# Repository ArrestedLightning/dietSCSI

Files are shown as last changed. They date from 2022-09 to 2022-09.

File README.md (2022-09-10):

dietSCSI logo

The dietSCSI is a SCSI disk emulator, designed to be low-cost while remaining highly functional.

Features
----------

* SMT-first design, optimized for modern low-cost assembly services
  * Target price of ~$10 each in small quantities from JLCPCB, fully assembled
  * This implies that the retail price for a fully-assembled board could be $20 with a 100% markup
* Can be [hand-assembled](https://youtu.be/Q2M2qIhKqx8) using only parts that are [readily available from DigiKey](https://www.digikey.com/short/dphdzd52) (Except for the STM32 microcontroller, but those aren't readily available anywhere at the moment)
* Integrated DB25 and 50-pin IDC connectors on one board.  A single PCB design covers multiple use cases, ideal for easy switching between multiple computers
  * This also means that you can use the dietSCSI itself as a DB-25 to 50-pin SCSI adapter in a pinch
* On-board termination (jumper-selectable)
* Design files for [3D printed cases](https://github.com/ArrestedLightning/dietSCSI/blob/main/Mechanical/README.md) are available in variants for both portable usage and 3.5" hard disk replacement
* 0.1" headers for external activity LEDs
* Can be powered via SCSI termination power or from an external source
* Designed to run firmware based on the open source [BlueSCSI firmware](https://github.com/erichelgeson/BlueSCSI/)
* [Default firmware](https://github.com/ArrestedLightning/dietSCSI_firmware/) has both [USB image passthrough](https://youtu.be/Y3mzckQU518) and [USB firmware update support](https://youtu.be/odwWRFDpAHM) built in (see the [usage page](https://github.com/ArrestedLightning/dietSCSI/blob/main/docs/usage.md) for details).

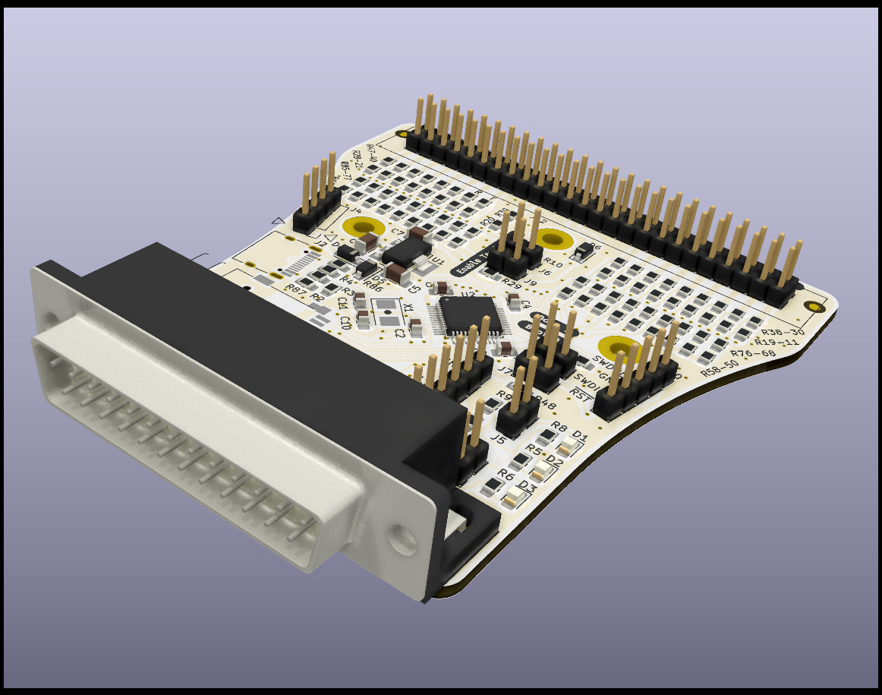
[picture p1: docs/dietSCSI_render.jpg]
dietSCSI PCB image


Documentation
--------
* [Ordering assembled boards from JLCPCB](https://github.com/ArrestedLightning/dietSCSI/blob/main/docs/ordering_boards.md)
* [Hand assembly](https://github.com/ArrestedLightning/dietSCSI/blob/main/docs/hand_assembly.md)
* [Finishing](https://github.com/ArrestedLightning/dietSCSI/blob/main/docs/finishing.md)
* [Usage](https://github.com/ArrestedLightning/dietSCSI/blob/main/docs/usage.md)
* [Test Results](https://github.com/ArrestedLightning/dietSCSI/blob/main/docs/testresults.md)

Acknowledgments
--------

* The [ARDSCSuino-stm32](https://github.com/ztto/ArdSCSino-stm32) project for the original implementation of STM32-to-SCSI hardware and firmware
* [This TI document](https://www.ti.com/lit/an/slla035/slla035.pdf) on SCSI termination
* The [BlueSCSI project](https://github.com/erichelgeson/BlueSCSI/) for their work on the firmware

BlueSCSI is a registered trademark.  This project is not affiliated with or endorsed by the BlueSCSI project.  Please do not contact the BlueSCSI people for support; use GitHub discussions or email me directly.

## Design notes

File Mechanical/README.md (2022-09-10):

Cases
==================
Several 3D-printable case options are available for the dietSCSI.  Cases were designed using FreeCAD; all designs are in the same CAD file.  You will need 4 M3x5mm machine screws to attach the board to the case and hold on the lid.  The internal versions are also designed to use M3 screws for the mounting fasteners.

Portable
---------

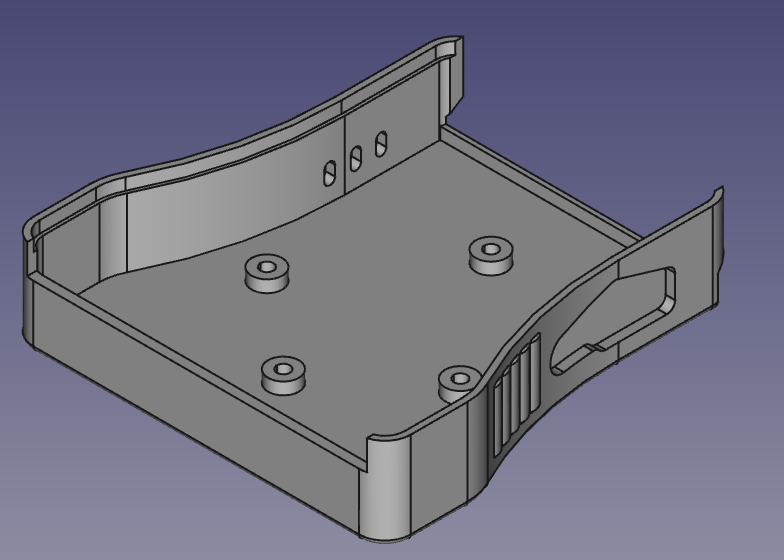
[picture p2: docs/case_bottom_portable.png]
Portable case render


This case is designed for external use.  It could also be used internally if mounted using velcro or adhesive tape.

3.5" Compact
--------
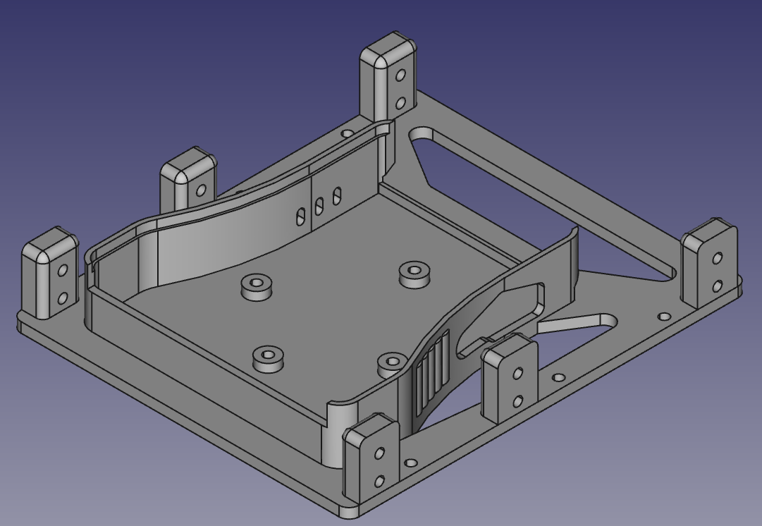
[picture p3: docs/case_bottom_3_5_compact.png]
3.5 compact case render


This case is designed for internal use.  It is smaller so it is printable on smaller printers.  Its size is more or less constrained by the standard 3.5" drive mounting holes.  This means that it will sit further in compared to a real hard drive.  If your SCSI cable is only just long enough for a standard drive, it may not work with this enclosure.  The standard SCSI cable included with a Macintosh Classic II is just barely long enough to reach when using this enclosure.  Mounting holes are available on both the sides and the bottom, allowing for mounting options that should work with most computers.

3.5" Extended
--------
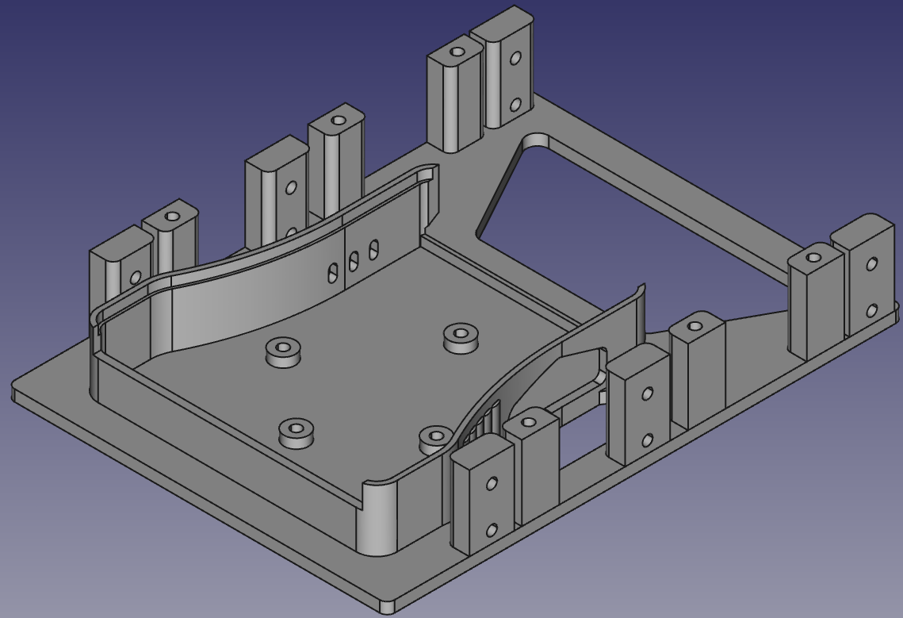
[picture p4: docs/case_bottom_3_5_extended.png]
3.5 extended case render


This case is also designed for internal use.  It is designed to be closer to the size of a standard 3.5" drive, which means that the SCSI connector should come just about up to the edge.  This should be more compatible with more systems.  It is also designed so that it can be mounted upside down using either the side or the bottom mounting holes, which may be necessary to get the SCSI connector in the correct orientation.  In particular, this feature was designed with the Macintosh LC family in mind.  I have not tested this, though, so I can't guarantee it will fit.

Lids
--------
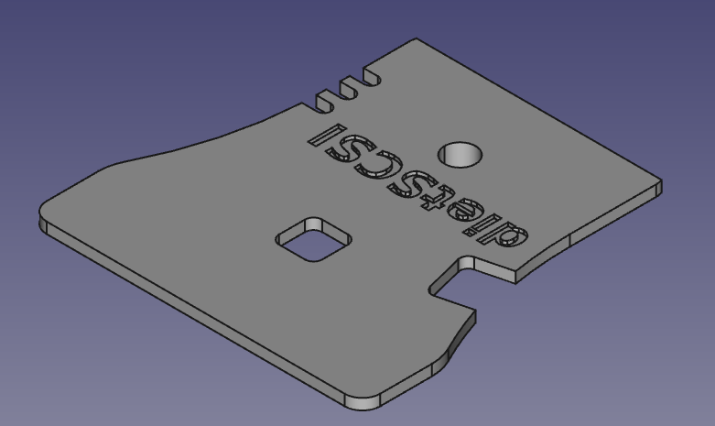
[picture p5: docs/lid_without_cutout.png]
Lid without cutout


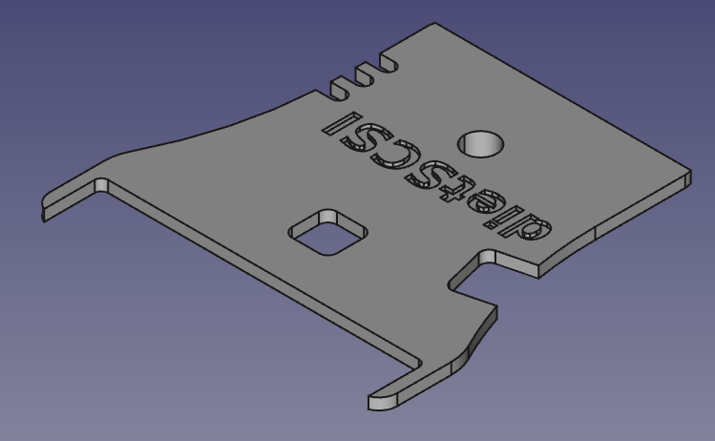
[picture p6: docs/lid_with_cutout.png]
Lid with cutout


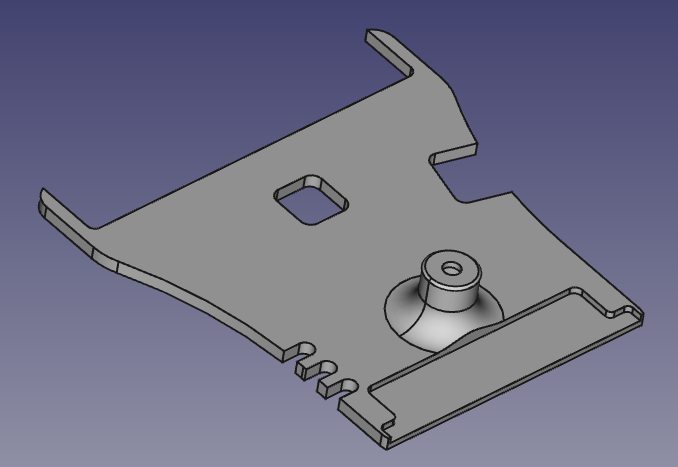
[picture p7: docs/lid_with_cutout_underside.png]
Lid with cutout underside view


All of the above case designs use the same lid.  There are two lid options available, one with a cutout for the SCSI ribbon cable, and one without the cutout.  The cutout is suggested for most people, as it makes more functionality available to you, but if you are putting together a portable version and you are 100% sure that you will only ever be using the DB25 connector, the "without cutout" version does give a cleaner appearance.

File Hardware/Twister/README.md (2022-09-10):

SCSI Twister
==========
Some SCSI-based machines (e.g. the Mac LC series) expect their hard drive to be mounted such that the 50-pin connector ends up reversed compared to what the dietSCSI board expects.  The SCSI Twister is a simple board that I designed to flip the SCSI connection around to make it easier to install the dietSCSI board in those machines.  After designing it, I decided that I would prefer not to introduce any additional boards if at all possible, and instead modified the case design to allow the board to be installed upside down.  I have never built this board, and can therefore make no promises as to its functionality.  It is included here for the sake of completeness only.

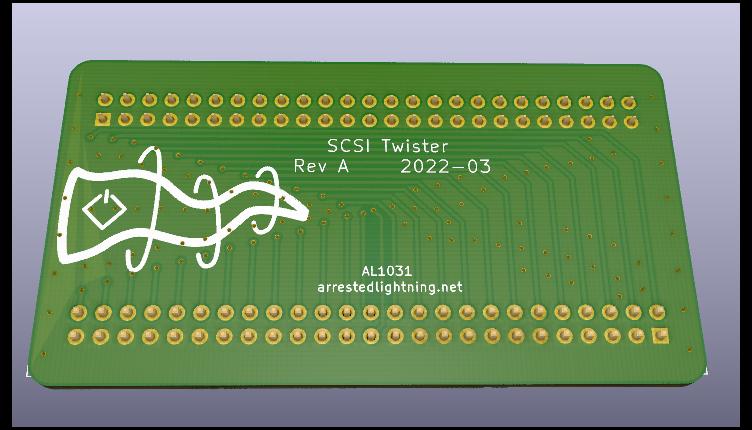
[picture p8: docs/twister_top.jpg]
SCSI Twister PCB top


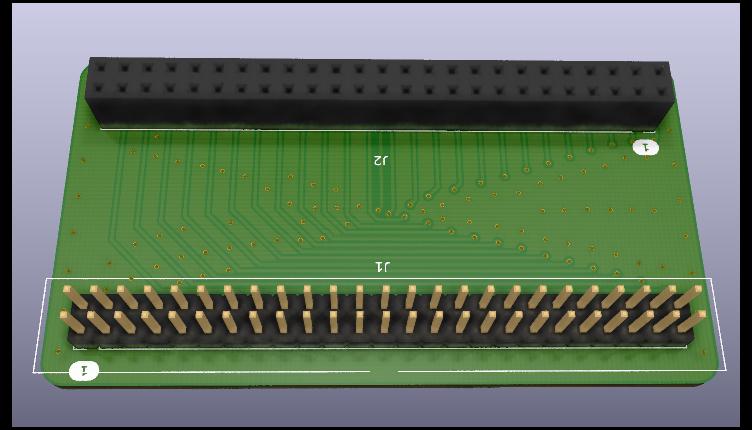
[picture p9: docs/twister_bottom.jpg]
SCSI Twister PCB top


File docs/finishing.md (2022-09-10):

DB-25
==========

There are two main types of DB-25 connectors out there.  Some of them have the metal outer shell crimped on; it will stay in place without any screws or standoffs installed.  If this is the type you have on your board, congratulations, you're done with this step!  The other type of connector uses the threaded standoffs on either side of the connector pins to hold the metal shell in place.  This type is generally what you'll get if you have JLCPCB assemble your boards.  Unfortunately, those threaded standoffs have to go if you want to be able to plug your dietSCSI directly into the back of your computer.  If you are absolutely sure you won't need the DB-25 connector (e.g. you plan to permanently install your dietSCSI inside a computer), you technically don't have to do anything here.  However, I would suggest doing it now, while you're thinking about it, regardless.  That way it'll be ready to go in the future should you need an external SCSI device in a pinch.
The standoffs can be removed by loosening them with a pliers and carefully unscrewing them.  Be careful not to bend the pins on the connector while the shell is off.  The standoffs will then need to be replaced with some low-profile screws.  On most DB-25 connectors, the screw threads are SAE #4-40; 1/4" (6.35mm) length is more than sufficient to hold the shell in place.  If you don't have some of these on hand, you should be able to get them from most online or physical hardware stores.  Here is an option [from McMaster-Carr](https://www.mcmaster.com/92949A106/); I have also previously purchased them [from Amazon](https://smile.amazon.com/gp/product/B07TM4Y5CB/), but they appear to be out of stock as of this writing.

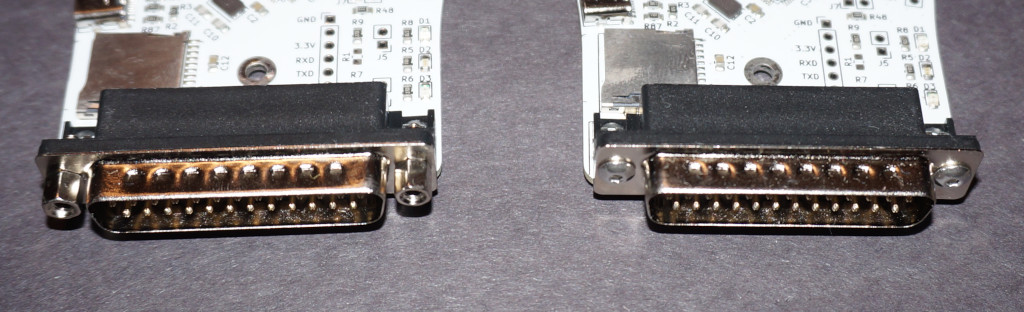
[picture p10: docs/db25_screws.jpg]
dietSCSI DB25 screws comparison


Testing
=========

Whether you assembled your dietSCSI board yourself or got it professionally assembled, it's a good idea to give it a quick visual inspection for assembly errors and solder bridges.  Once you are satisfied that there are no hardware issues, it's not a bad idea to try and power the board up in a controlled manner to check for electrical problems.  The best option is a bench power supply with a current limit function, if you have it.  Set it to 5V, 0.5A, and inject power into pins 1 and 2 of the Berg connector.  After powering the board up, verify that the power LED comes on and stays on, and there is no smoke.  The board should be drawing less than 200mA.  If everything looks good, you can move on to programming.  Otherwise, look over the board again, paying careful attention to component orientation, and checking for cracks and solder bridges.

Programming
==========

Now that your board is assembled, you need to get firmware onto it.

JTAG
----------

The most reliable way to get firmware on to your board is using JTAG.  You can get cheap ST-LINK V2 sticks off of Amazon/eBay/Aliexpress for a few dollars; they're virtually all the same.  J10 is the JTAG connector on the dietSCSI board.  Only the first four pins are necessary for programming.  They are in the same order as the corresponding pins on the ST-LINK.  If you'd like, you can solder a 0.1" header into the dietSCSI board.  This would let you use a ribbon cable or female-female dupont wire to connect the ST-LINK to the board.  However, I've found that using male-female dupont wire that's taped into a bundle of 4 is sufficient to make good contact as long as it's inserted and held in at an angle.

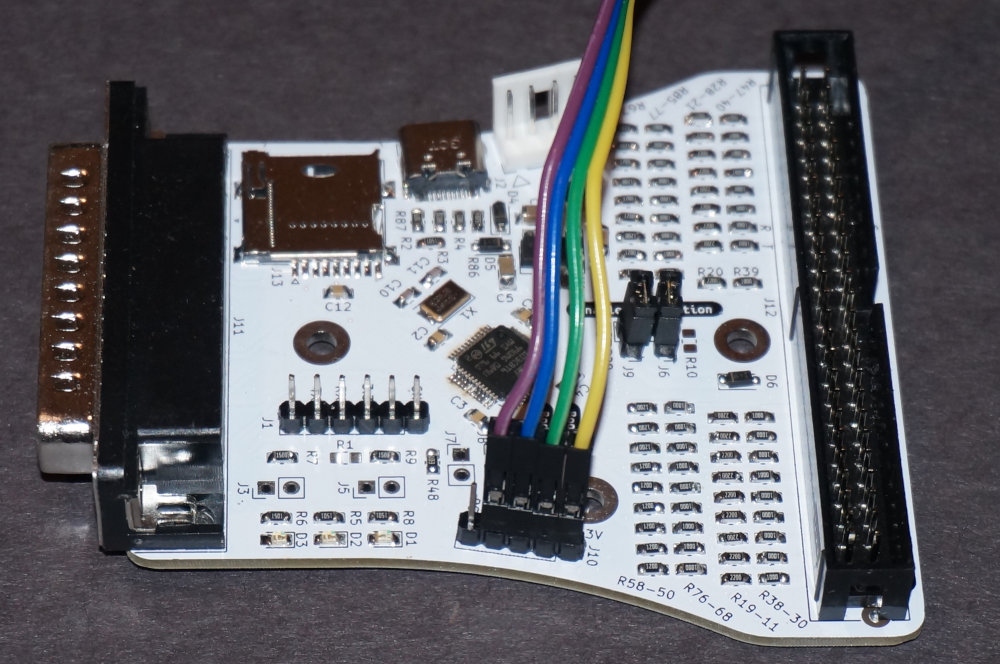
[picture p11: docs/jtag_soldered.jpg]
dietSCSI JTAG connector soldered in


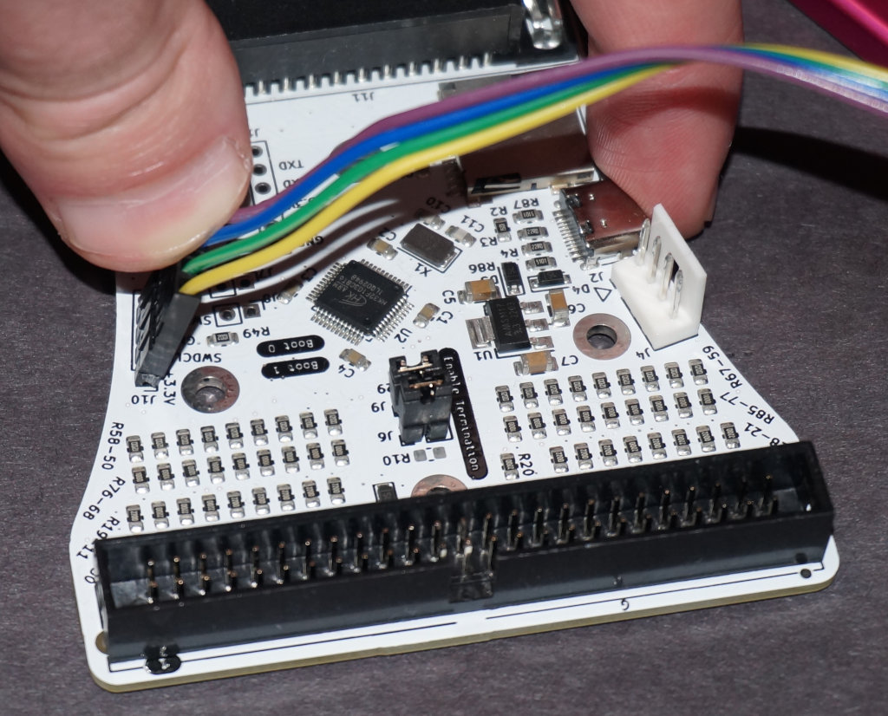
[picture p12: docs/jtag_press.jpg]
dietSCSI JTAG connector pressed in


The first time you program the board, no additional steps should be necessary.  On subsequent programmings, you will need to put the chip into bootloader mode by shorting out the BOOT0 pins.  This can be done by jamming a tweezers or a piece of stiff wire in J7.  If you prefer, you can solder a 2-pin 0.1" header into J7 and install a jumper.

### From Source

1. Download and install [Visual Studio Code](https://code.visualstudio.com/).
2. Install [PlatformIO IDE](https://platformio.org/install/ide?install=vscode).
3. Download a copy of the firmware source code or check one out with git.
4. Open Visual Studio Code, then open the firmware source code folder using PlatformIO's "Open Project" command.
5. Connect the dietSCSI board to the computer using the ST-LINK adapter.
6. Click on the "PlatformIO: Upload" button in the lower left corner of the window.
7. Compiling and uploading the firmware should take a few seconds.  It will start running once the upload completes.  An error at this point is normal as the firmware disables the debug pins as soon as is starts.

### Using ST GUI

1. Download and install STM32CubeProg from https://www.st.com/en/development-tools/stm32cubeprog.html.
2. Download a copy of the firmware image in .bin or .hex format.
3. Open the STM32CubeProgrammer application and switch to the Erasing & Programming page using the controls on the left side of the window.
4. Click on File Path > Browse and select the firmware image.  It's not a bad idea to make sure the "Verify programming" option is selected.
5. Connect the ST-Link adapter to the dietSCSI board.  In the top right corner of the STM32CubeProgrammer window, make sure ST-LINK is selected and click connect.
6. Click on the "Start Programming" button and wait for the process to finish.

### Using Command Line

1. Download and install a copy of the stlink command line tools from https://github.com/stlink-org/stlink.  If you're on Linux, they are likely already available in your package manager (Under Ubuntu, try the `stlink-tools` package).
2. Download a copy of the firmware image in .bin or .hex format.
3. Connect the ST-Link adapter to the dietSCSI board.
4. Run the command `st-flash --flash=128k write '/path/to/firmware.bin' 0x8000000`.  Depending on the exact model of microcontroller you have, you may or may not need to omit the `--flash=128k` argument.  If you are using a hex format image, add the argument `--format=ihex` before `write`.

Serial
----------

It is also possible to program the board using a USB-TTL serial adapter.  This has been tested on both an original STM32 as well as the HK32 and GD32 clones, but it may not be supported on all clones.  A 3.3V TTL adapter is recommended, but a 5V adapter may also work.  The programming UART pins are available on the 50-pin SCSI connector, they are labeled G, R, and T for Ground, Receive, and Transmit, respectively.  They are labeled from the point of view of the dietSCSI board; unfortunately, not all serial adapters label their pins consistently.  If it doesn't work, try swapping the RX and TX pins.  If your serial adapter also has a 5V output pin, you can use this to power the board (attach to the middle pin in the bottom row), otherwise, use a USB cable to supply power.  The Boot0 jumper _must_ be shorted when connecting power in order to put the board into serial programming mode.  I have also found that this process works much more reliably with the termination jumpers removed.

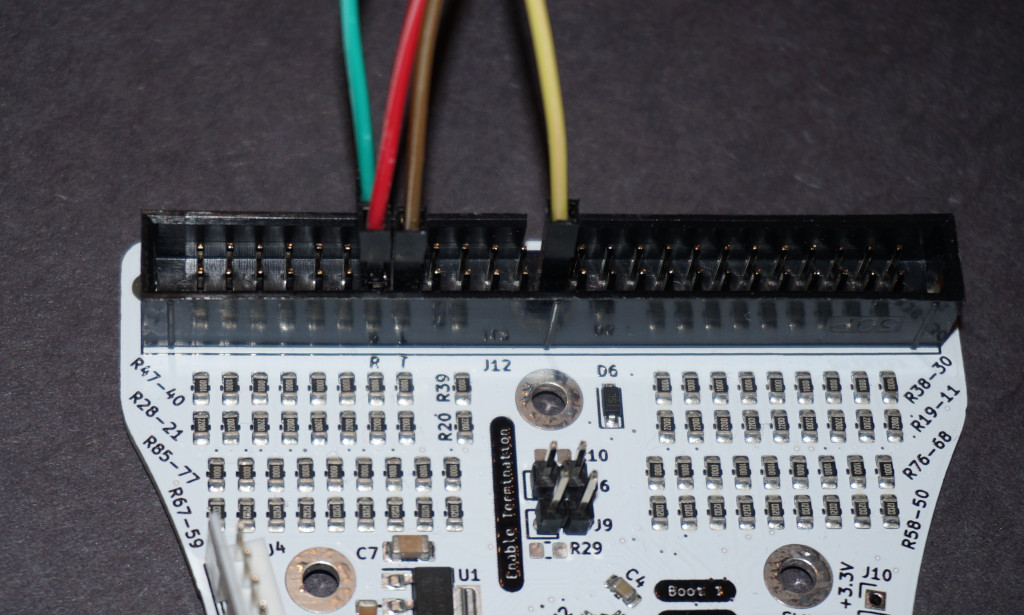
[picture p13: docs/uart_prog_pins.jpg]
dietSCSI UART programming pins


### Using ST GUI

1. Download and install STM32CubeProg from https://www.st.com/en/development-tools/stm32cubeprog.html.
2. Download a copy of the firmware image in .bin or .hex format.
3. Open the STM32CubeProgrammer application and switch to the Erasing & Programming page using the controls on the left side of the window.
4. Click on File Path > Browse and select the firmware image.  It's not a bad idea to make sure the "Verify programming" option is selected.
5. Connect the TTL serial adapter to the dietSCSI board.  Apply power to the board while shorting the Boot0 jumper.  In the top right corner of the STM32CubeProgrammer window, make sure UART is selected.  Choose the port corresponding to your adapter and click connect.  I have found that this will occasionally fail the first time you try to connect.  If it fails, try just clicking connect again.  Otherwise, you may have RX and TX backwards; try swapping them.
6. Click on the "Start Programming" button and wait for the process to finish.

Cases
==========

Several cases are available for 3D printing, depending on how you intend to use your dietSCSI device.  Check out the [README in the mechanical directory](https://github.com/ArrestedLightning/dietSCSI/blob/main/mechanical/README.md) for more information.

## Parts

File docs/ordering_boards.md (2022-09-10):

Ordering Assembled Boards
=============

This board is optimized for assembly at JLCPCB's low-cost PCB assembly service.  The process is pretty simple:

1. Download the following files from Hardware/Main/\<current rev\>/dietSCSI: **AL1030 \<rev\>.zip**, **dietSCSI\_bom\_jlc.csv**, and **dietSCSI\_cpl\_jlc.csv**.
2. Go to https://jlcpcb.com/
3. Create an account or log in if you already have an account.
4. Click on Order Now in the upper right corner of the page.
5. Click on the "Add gerber file" button near the center of the page.
6. Select the zip file you downloaded earlier and upload it.
7. Select your options.  Here you can select the quantity of boards you wish to order.  Most default settings should be OK, but it is suggested to change the PCB color to white.
8. Scroll down to the _PCB Assembly_ section of the page and turn the switch on.  Select _Assemble top side_.  The other default settings should not need to be changed.  Click on Confirm.
9. Click on _Add BOM File_ and upload the _bom_ file you downloaded earlier.
10. Click on _Add CPL File_ and upload the _cpl_ file you downloaded earlier.
11. Under the Usage Description field, select an appropriate description from the list.
12. Click Next.
13. You will be taken to the Select Parts page.  Look for any parts that have "Inventory Shortage" listed in the rightmost column.  Click on the magnifying glass and search for an alternate part (see "Component Substitutions" below).
14. Once you have selected any necessary substitute parts, click next at the bottom of the page.
15. Scroll to the bottom of the page and make sure there are no parts under the "Unselected parts" heading.
16. Click on "Save to Cart".
17. Go through the checkout process.
18. Wait for your boards to arrive!
19. Once your boards arrive, proceed to the [Finishing](https://github.com/ArrestedLightning/dietSCSI/blob/main/docs/finishing.md) page.

Component Substitutions
============
Various components may not be in stock when you are ready to place your order.  Passive components like resistors or capacitors can generally be replaced with any part of the same value and package.  Some substitutes for more complex parts such as connectors are listed on the schematic.  There are several options for the main microcontroller that are more or less compatible with the original part, but for maximum functionality, sticking with the original STM32F103 part is recommended.  For example, the HK32F103 parts are known to have unusable USB hardware, and have difficulty communicating with SD cards at full speed, which reduces maximum throughput.

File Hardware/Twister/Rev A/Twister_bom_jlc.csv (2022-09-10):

Comment | Designator | Footprint | LCSC Part #
Conn_02x25_Odd_Even | J1 | PinHeader_2x25_P2.54mm_Vertical_Shrouded | C601945
Conn_02x25_Odd_Even | J2 | PinSocket_2x25_P2.54mm_Vertical | C40024

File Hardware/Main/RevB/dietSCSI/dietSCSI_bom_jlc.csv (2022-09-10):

Comment | Designator | Footprint | LCSC Part #
0.1uF | C4,C2,C1,C3,C12 | C_0805_2012Metric_Pad1.18x1.45mm_HandSolder | C49678
10uF | C5,C6,C7 | C_1206_3216Metric_Pad1.33x1.80mm_HandSolder | C13585
20pF | C10,C11 | C_0805_2012Metric_Pad1.18x1.45mm_HandSolder | C1798
Red | D1 | LED_0805_2012Metric_Pad1.15x1.40mm_HandSolder | C84256
Green | D2 | LED_0805_2012Metric_Pad1.15x1.40mm_HandSolder | C2297
Yellow | D3 | LED_0805_2012Metric_Pad1.15x1.40mm_HandSolder | C2296
D | D4,D5,D6 | D_SOD-123 | C8598
MC-107DM | J2 | USB_C_Receptacle_XKB_U262-16XN-4BVC11 | C2874569
Conn_01x04_Male | J4 | BERG_4PIN | C210162
Jumper | J9,J6 | PinHeader_1x02_P2.54mm_Vertical | C2894925
DB25_Male_MountingHoles | J11 | DSUB-25_Male_Horizontal_P2.77x2.84mm_EdgePinOffset7.70mm_Housed_MountingHolesOffset9.12mm | C190082
Conn_02x25_Odd_Even | J12 | PinHeader_2x25_P2.54mm_Vertical_Shrouded | C601945
TF115 | J13 | TF-015_MEM2075_HYBRID | C266620
1.5K | R2 | R_0805_2012Metric_Pad1.20x1.40mm_HandSolder | C4310
22 | R3,R4 | R_0805_2012Metric_Pad1.20x1.40mm_HandSolder | C17561
5.1K | R5,R86,R87 | R_0805_2012Metric_Pad1.20x1.40mm_HandSolder | C27834
2.7K | R6,R8,R9,R7 | R_0805_2012Metric_Pad1.20x1.40mm_HandSolder | C17530
220 | R18,R17,R16,R15,R14,R13,R12,R11,R19,R20,R21,R22,R23,R24,R25,R26,R27,R28 | R_0805_2012Metric_Pad1.20x1.40mm_HandSolder | C17557
100 | R37,R36,R35,R34,R33,R32,R31,R30,R38,R39,R40,R41,R42,R43,R44,R45,R46,R47,R75,R74,R73,R72,R71,R70,R69,R68,R76,R77,R78,R79,R80,R81,R82,R83,R84,R85 | R_0805_2012Metric_Pad1.20x1.40mm_HandSolder | C17408
10K | R49,R48 | R_0805_2012Metric_Pad1.20x1.40mm_HandSolder | C17414
120 | R57,R56,R55,R54,R53,R52,R51,R50,R58,R59,R60,R61,R62,R63,R64,R65,R66,R67 | R_0805_2012Metric_Pad1.20x1.40mm_HandSolder | C17437
LM1117-3.3 | U1 | SOT-223-3_TabPin2 | C6186
GD32F103CBT6 | U2 | LQFP-48_7x7mm_P0.5mm | C77979
8MHz | X1 | Crystal_SMD_5032-2Pin_5.0x3.2mm | C115962

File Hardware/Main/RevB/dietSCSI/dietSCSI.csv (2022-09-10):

Reference | Quantity | Value | Footprint | Datasheet | DIGIKEY | JLCPCB
C10 C11 | 2 | 20pF | Capacitor_SMD:C_0805_2012Metric_Pad1.18x1.45mm_HandSolder |  | 738-CML0805C0G200JT50VCT-ND | C1798
C1 C2 C3 C4 C12 | 5 | 0.1uF | Capacitor_SMD:C_0805_2012Metric_Pad1.18x1.45mm_HandSolder |  | 1276-1003-1-ND | C49678
C5 C6 C7 | 3 | 10uF | Capacitor_SMD:C_1206_3216Metric_Pad1.33x1.80mm_HandSolder |  | 1276-6736-1-ND | C13585
D1 | 1 | Red | LED_SMD:LED_0805_2012Metric_Pad1.15x1.40mm_HandSolder | ~ | 754-1132-1-ND | C84256
D2 | 1 | Green | LED_SMD:LED_0805_2012Metric_Pad1.15x1.40mm_HandSolder | ~ | 754-1131-1-ND | C2297
D3 | 1 | Yellow | LED_SMD:LED_0805_2012Metric_Pad1.15x1.40mm_HandSolder | ~ | 754-1134-1-ND | C2296
D4 D5 D6 | 3 | D | Diode_SMD:D_SOD-123 | ~ | B5819W-TPMSCT-ND | C8598
H1 H2 H3 H4 | 4 | FIDUCIAL | Fiducial:Fiducial_1.5mm_Mask3mm
H5 H6 H7 H8 | 4 | MountingHole | MountingHole:MountingHole_3mm_Pad | ~
J1 | 1 | Conn_01x06 | Connector_PinHeader_2.54mm:PinHeader_1x06_P2.54mm_Vertical | ~
J10 | 1 | Conn_01x05 | Connector_PinHeader_2.54mm:PinHeader_1x05_P2.54mm_Vertical | ~
J11 | 1 | DB25_Male_MountingHoles | Connector_Dsub:DSUB-25_Male_Horizontal_P2.77x2.84mm_EdgePinOffset7.70mm_Housed_MountingHolesOffset9.12mm | ~ | 2057-DB25-PL-24-ND | C190082
J12 | 1 | Conn_02x25_Odd_Even | AL_Footprints:PinHeader_2x25_P2.54mm_Vertical_Shrouded | ~ | ED10530-ND | C601945
J13 | 1 | TF115 | AL_Footprints:TF-015_MEM2075_HYBRID |  | 2073-MEM2075-00-140-01-ACT-ND | C266620
J2 | 1 | MC-107DM | Connector_USB:USB_C_Receptacle_XKB_U262-16XN-4BVC11 | https://www.usb.org/sites/default/files/documents/usb_type-c.zip | 664-12402012E212ACT-ND | C2874569
J4 | 1 | Conn_01x04_Male | AL_Footprints:BERG_4PIN | ~ | A106197-ND | C210162
J3 J5 J7 J8 | 4 | Conn_01x02_Male | Connector_PinHeader_2.54mm:PinHeader_1x02_P2.54mm_Vertical | ~
J6 J9 | 2 | Jumper | Connector_PinHeader_2.54mm:PinHeader_1x02_P2.54mm_Vertical | ~ | 2057-PH1-02-UA-ND | C2894925
R1 R10 R29 | 3 | 0-DNP | Resistor_SMD:R_0805_2012Metric_Pad1.20x1.40mm_HandSolder
R11 R12 R13 R14 R15 R16 R17 R18 R19 R20 R21 R22 R23 R24 R25 R26 R27 R28 | 18 | 220 | Resistor_SMD:R_0805_2012Metric_Pad1.20x1.40mm_HandSolder | ~ | RMCF0805FT220RCT-ND | C17557
R2 | 1 | 1.5K | Resistor_SMD:R_0805_2012Metric_Pad1.20x1.40mm_HandSolder |  | RMCF0805FT1K50CT-ND | C4310
R3 R4 | 2 | 22 | Resistor_SMD:R_0805_2012Metric_Pad1.20x1.40mm_HandSolder |  | RMCF0805FT22R0CT-ND | C17561
R30 R31 R32 R33 R34 R35 R36 R37 R38 R39 R40 R41 R42 R43 R44 R45 R46 R47 R68 R69 R70 R71 R72 R73 R74 R75 R76 R77 R78 R79 R80 R81 R82 R83 R84 R85 | 36 | 100 | Resistor_SMD:R_0805_2012Metric_Pad1.20x1.40mm_HandSolder | ~ | RMCF0805FT100RCT-ND | C17408
R48 R49 | 2 | 10K | Resistor_SMD:R_0805_2012Metric_Pad1.20x1.40mm_HandSolder |  | RMCF0805JT10K0CT-ND | C17414
R5 R86 R87 | 3 | 5.1K | Resistor_SMD:R_0805_2012Metric_Pad1.20x1.40mm_HandSolder |  | RMCF0805FT5K10CT-ND | C27834
R50 R51 R52 R53 R54 R55 R56 R57 R58 R59 R60 R61 R62 R63 R64 R65 R66 R67 | 18 | 120 | Resistor_SMD:R_0805_2012Metric_Pad1.20x1.40mm_HandSolder | ~ | 738-RMCF0805FT120RCT-ND | C17437
R6 R7 R8 R9 | 4 | 2.7K | Resistor_SMD:R_0805_2012Metric_Pad1.20x1.40mm_HandSolder |  | RMCF0805FT2K70CT-ND | C17530
U1 | 1 | LM1117-3.3 | Package_TO_SOT_SMD:SOT-223-3_TabPin2 | http://www.ti.com/lit/ds/symlink/lm1117.pdf | AZ1117IH-3.3TRG1DICT-ND | C6186
U2 | 1 | GD32F103CBT6 | Package_QFP:LQFP-48_7x7mm_P0.5mm |  | 497-17380-1-ND | C77979
X1 | 1 | 8MHz | Crystal:Crystal_SMD_5032-2Pin_5.0x3.2mm |  | XC2103CT-ND | C115962

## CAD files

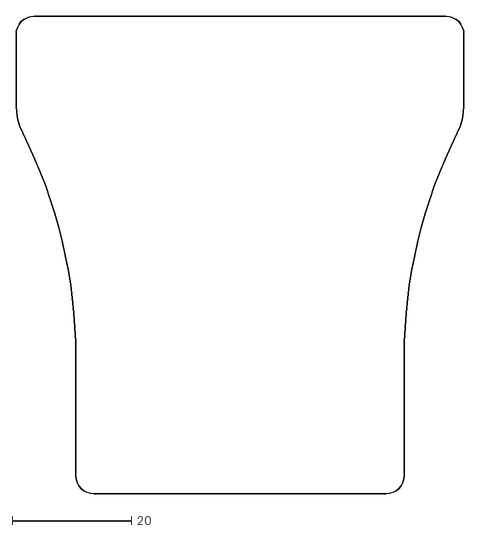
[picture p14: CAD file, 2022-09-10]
Hardware/Main/RevB/Mechanical/Board Outline-Sketch.dxf
75.0 x 80.0

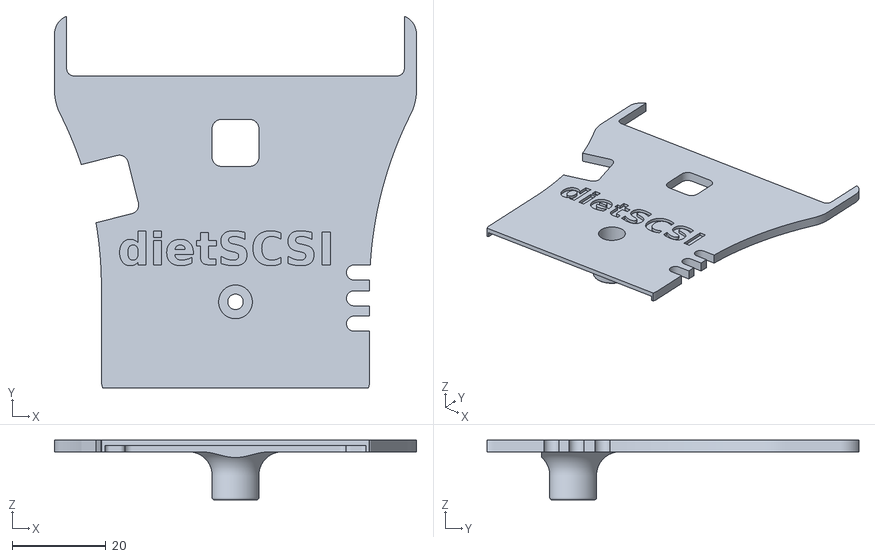
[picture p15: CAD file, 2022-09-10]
Mechanical/Case Lid With Ribbon Cutout and DB25.stl
77.2 x 79.2 x 12.8

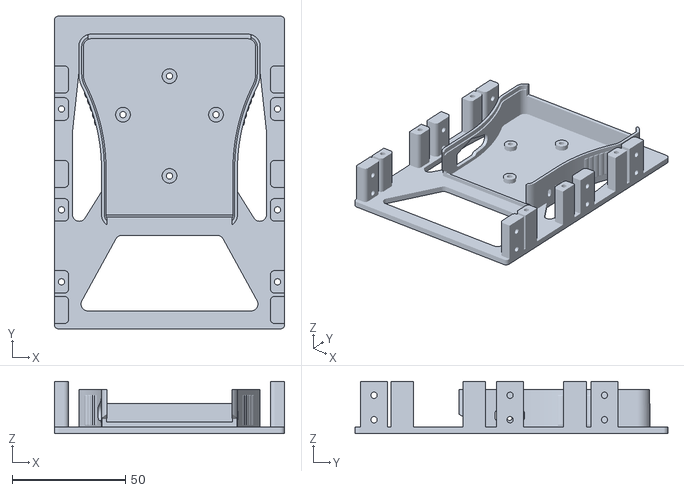
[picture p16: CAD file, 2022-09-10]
Mechanical/CaseBottom3.5 Extended v1.10.stl
101.6 x 138.0 x 23.0

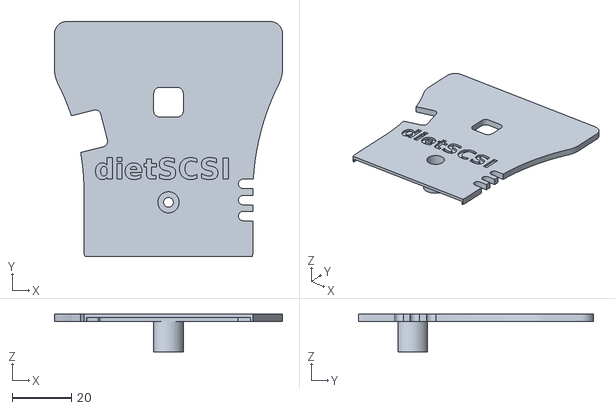
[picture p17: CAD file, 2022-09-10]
Mechanical/Case Lid Without Ribbon Cutout and DB25.stl
77.2 x 79.5 x 12.8

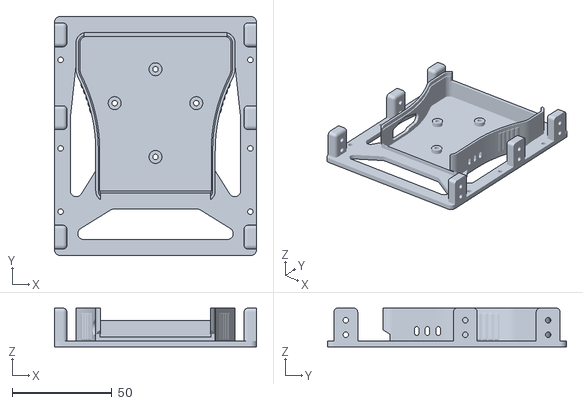
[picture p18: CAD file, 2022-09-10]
Mechanical/CaseBottom3.5 Compact v1.10.stl
101.6 x 120.0 x 19.5

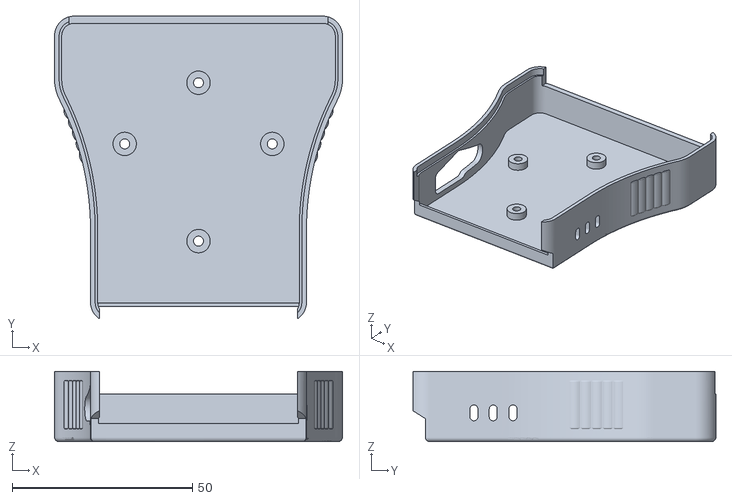
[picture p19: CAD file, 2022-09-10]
Mechanical/Case Bottom Portable.stl
80.0 x 84.1 x 19.5

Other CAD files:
Hardware/Main/RevB/Mechanical/Board Outline.FCStd
Hardware/Main/RevA/Mechanical/Board Outline.FCStd

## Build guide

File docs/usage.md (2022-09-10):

Termination
===========
Parallel SCSI devices typically require at least one, but no more than two, device(s) on the bus to have termination enabled.  Best practice is to enable termination on devices at the ends of the SCSI bus.  For an internal device, you will almost always want termination to be enabled.  For an external device, you will also usually want termination enabled, but you may need to disable it if other devices on the bus also provide termination.

SCSI devices are notorious for being sensitive to termination issues; sometimes the only way to resolve issues is trial and error.  If you are having issues with SCSI device reliability, try disabling termination if it is enabled, or enabling it if it is disabled.  On may Macintosh machines, the internal SCSI hard drive is on the same bus as the external SCSI port, and the internal hard drive will typically have termination enabled, so you may already have one terminated device on the bus without realizing it.  Counterintuitively, sometimes adding more SCSI devices to the bus, such as a ZIP drive, may actually improve the stability of the bus.

SCSI Addressing
===========
8-bit SCSI allows for up to 8 devices on the bus (i.e. IDs 0 - 7).  On Macintosh systems, the internal hard disk is typically assigned to SCSI ID 0, and an internal CD-ROM drive is typically assigned to SCSI ID 3.  The computer itself will typically be at SCSI ID 7.  Other internal drives (Zip, Jazz, M-O, etc) will also consume SCSI IDs.  Connecting two devices with the same SCSI ID to the same SCSI ID will typically result in a computer that hangs up on boot.  If you are unsure which SCSI IDs are already in use on your computer, use a tool such as SCSIProbe to enumerate the existing SCSI devices.

Disk Images
===========
The standard firmware for the dietSCSI uses raw disk images to represent hard disks.  The naming of the disk images is used to configure disk and SCSI parameters.

The TL;DR version is this:

Images should be named like HD[ID][LUN]_[SS].hda. [ID] represents the SCSI id. [LUN] represents the SCSI LUN; 0 is the only value supported. [SS] is the sector size.  This will virtually always be 512, but could also be 256 or 1024 in certain circumstances.  Additional text in the file name is ignored and can be used to help identify disk images.  Disk images can be named using the extensions .hda or .img.  File names should be less than 32 characters.

Example disk image names:

HD10_512.hda

HD20_512 Mac OS.img

A nice prebuilt hard disk image with Mac OS and tons of apps and games for compact macs is https://archive.org/details/macpack-20210619.  Rename boot.vhd to something like HD10_512.hda.

You can also easily generate custom blank disk images using [Disk Jockey](https://bluescsi.onegeekarmy.eu/diskjockey/).

USB Passthrough Mode
===========
On units running USB-enabled firmware, USB passthrough mode is available.  When plugged into a computer's USB port, the same disk images that would be made available over the SCSI port will instead be made available to the computer over USB as separate USB disks.  If both your SCSI-equipped and USB-equipped computers can understand a common file system, this allows you to use the dietSCSI as a simple and convenient way to transfer files.  Note that USB and SCSI operation are mutually exclusive.  Plugging in both the SCSI and USB ports is not recommended, but doing so will result in the USB interface taking precedence over the SCSI interface.

USB passthrough mode adds a delay of around 1 second on startup as the device needs time to detect if it is connected to a USB host.  In my limited testing, I did not find this to cause any compatibility problems, but if it does, USB passthrough mode can be disabled by creating a file named `nousb` in the root directory of the SD card.

Currently on Windows hosts, only a single volume can be passed through over USB.  If additional volumes are present on the SD card, USB passthrough mode will not work at all under Windows.  On Mac OS or Linux hosts, all volumes will be passed through to the host as expected.  This will be fixed in a future firmware release.

A video demonstrating this feature is available here: https://youtu.be/Y3mzckQU518.

USB Firmware Updates
==========
On units running USB-equipped firmware, the device's firmware can be updated using the USB port, without requiring any additional hardware such as an ST-LINK programmer.  This is possible due to the built-in [STM32duino bootloader](https://github.com/ArrestedLightning/STM32duino-bootloader). To update the firmware in the device, bridge the pins labeled "Boot 1" using a tweezers or piece of wire, or solder in a two-pin header and install a jumper.  Then plug in the USB cable.  The red LED (D1) should start to flash.
The firmware is updated using the `dfu-util` command.  The command you will use should look something like `dfu-util -D firmware.bin`.  The `-R` flag can be added to reboot the device automatically after the update completes.  This process has been tested on Linux, but it should also be possible under Mac OS and Windows.  After updating, check the `LOG.txt` file on the SD card to verify that the new firmware version was installed successfully.

A video demonstrating this feature is available here: https://youtu.be/odwWRFDpAHM.

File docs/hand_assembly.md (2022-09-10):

In a world where professional assembly of well-optimized boards costs basically nothing, you shouldn't have to assemble these boards by hand - no one should.  This is the main reason why this project exists.  Nevertheless, should you wish to hand-assemble this board for some reason, you certainly have that option.

Ordering Boards
=============

Zipped Gerber files are available in the project folder for each released revision of the board.  They should be ready to upload to your favorite PCB manufacturer such as JLCPCB, PCBWay, OSH Park, etc.  The boards should be ordered in 1.6mm (0.062") thickness, which should be the standard thickness just about everywhere.  White solder mask is suggested, but obviously not functionally required.  The surface finish is also up to you; HASL seems to work fine for these boards.

Ordering Parts
=============

The BOM for the board is provided as a CSV file in the project folder for each released revision of the board.  It contains part numbers for both LCSC and DigiKey.  I'm not opposed to adding other distributors' part numbers if there is interest in that as well.  A shared DigiKey cart containing the parts you need is available [here](https://www.digikey.com/short/dphdzd52).  Unfortunately, given the current state of the global electronic component market (as of mid-2022), parts are likely to go in and out of stock all the time, and the STM32 microcontroller is straight up unobtainable via authorized distributors.  A list of some substitutes for parts that are likely to go out of stock is included below.  If there are other parts you are unsure about substitutes for, feel free to open an issue or post about it on the discussions page.

|Reference|Description|Alternates|
|---|---|---|
|J11|DB25 right angle male connector|DB25-PL-24, A-DS 25 A/KG-T4S|
|D4, D5, D6|Schottky Diode, 40V/1A, SOD-123|MBRX120LF-TP, SBA130AS\_R1\_00001, B5819W-TP|
|J2|USB 2.0 Type-C connector|12402012E212A, USB4105-GF-A|
|U1|3.3V linear regulator, SOT223, 1117 pinout|LM1117MPX-33NOPB, AZ1117IH-3.3TRG1, LDL1117S33R, NCP1117ST33T3G|

Assembling The Board
=============
This board is designed with primarily surface-mount components.  In order to assemble this board, some familiarity with surface-mount soldering is required.  A soldering iron with a fine point, some 0.3mm solder, and a magnifier or microscope are also helpful.  There are a number of videos on how to solder surface-mount components; here are a few that look reasonable:

https://www.youtube.com/watch?v=b9FC9fAlfQE

https://www.youtube.com/watch?v=hoLf8gvvXXU

https://www.youtube.com/watch?v=f9fbqks3BS8

https://www.youtube.com/watch?v=EW9Y8rDm4kE

[This](https://youtu.be/Q2M2qIhKqx8) is a time-lapse of the actual assembly of two copies of this board.  This is by no means the only order in which components can be installed, but I think it's a pretty reasonable one.  If nothing else, I would definitely suggest installing the fine-pitch parts (the microcontroller, USB connector, and SD card slot) first, and the large through-hole connectors last.

An interactive HTML BOM is also provided in the file ibom.html.  This provides a mapping between component values and their location on the board, which I have found to be very helpful when hand-assembling boards.

Once you've finished assembling the board, proceed to the [finishing page](https://github.com/ArrestedLightning/dietSCSI/blob/main/docs/finishing.md).

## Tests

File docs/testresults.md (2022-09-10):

Functionality
==========
The dietSCSI has been tested for at least basic functionality on the following computers/devices:

| Device | OS | Result |
|---|---|---|
| Macintosh Classic II | System 7.1.2, System 7.5.5 | Works  |
| Macintosh Performa 630CD | System 7.5.5, Mac OS 8.1 | Works  |
| Power Macintosh G4 with Adaptec 2906 PCI SCSI card | Mac OS 9.2.2, Mac OS 10.4, Mac OS 10.5 | Works  |
| Generic Pentium PC with HP 53C416 ISA SCSI card | Windows 98 | Works  |

Performance
==========
All testing was done on a Macintosh Performa 630CD using firmware 1.1-SNAPSHOT-20220107.  Data was gathered using TimeDrive 2.0.3.

| SD_Card | Card_Format | MCU | OS | Latency  | Average_Seek | Max_Seek | Write | Read |
|---|---|---|---|---|---|---|---|---|
| Gigastone High Endurance 8GB | exFAT | GD32F103 | System 7.5.5 | 2.714 ms | 26.136 ms | 75.190 ms  | 1169 KB/s | 1160 KB/s |
| Gigastone High Endurance 8GB | exFAT | GD32F103 | Mac OS 8.1 | 2.633 ms | 25.244 ms | 75.333 ms  | 1162 KB/s | 1159 KB/s |
| Patriot 32GB | exFAT | GD32F103 | System 7.5.5 | 2.639 ms | 25.657 ms | 75.232 ms  | 1160 KB/s | 1161 KB/s |
| Gigastone High Endurance 8GB | exFAT | HK32F103 | System 7.5.5 | 3.318 ms | 40.315 ms | 115.728 ms | 859 KB/s  | 917 KB/s  |
| Patriot 32GB | exFAT | HK32F103 | System 7.5.5 | 3.240 ms | 39.864 ms | 115.836 ms | 856 KB/s  | 918 KB/s  |

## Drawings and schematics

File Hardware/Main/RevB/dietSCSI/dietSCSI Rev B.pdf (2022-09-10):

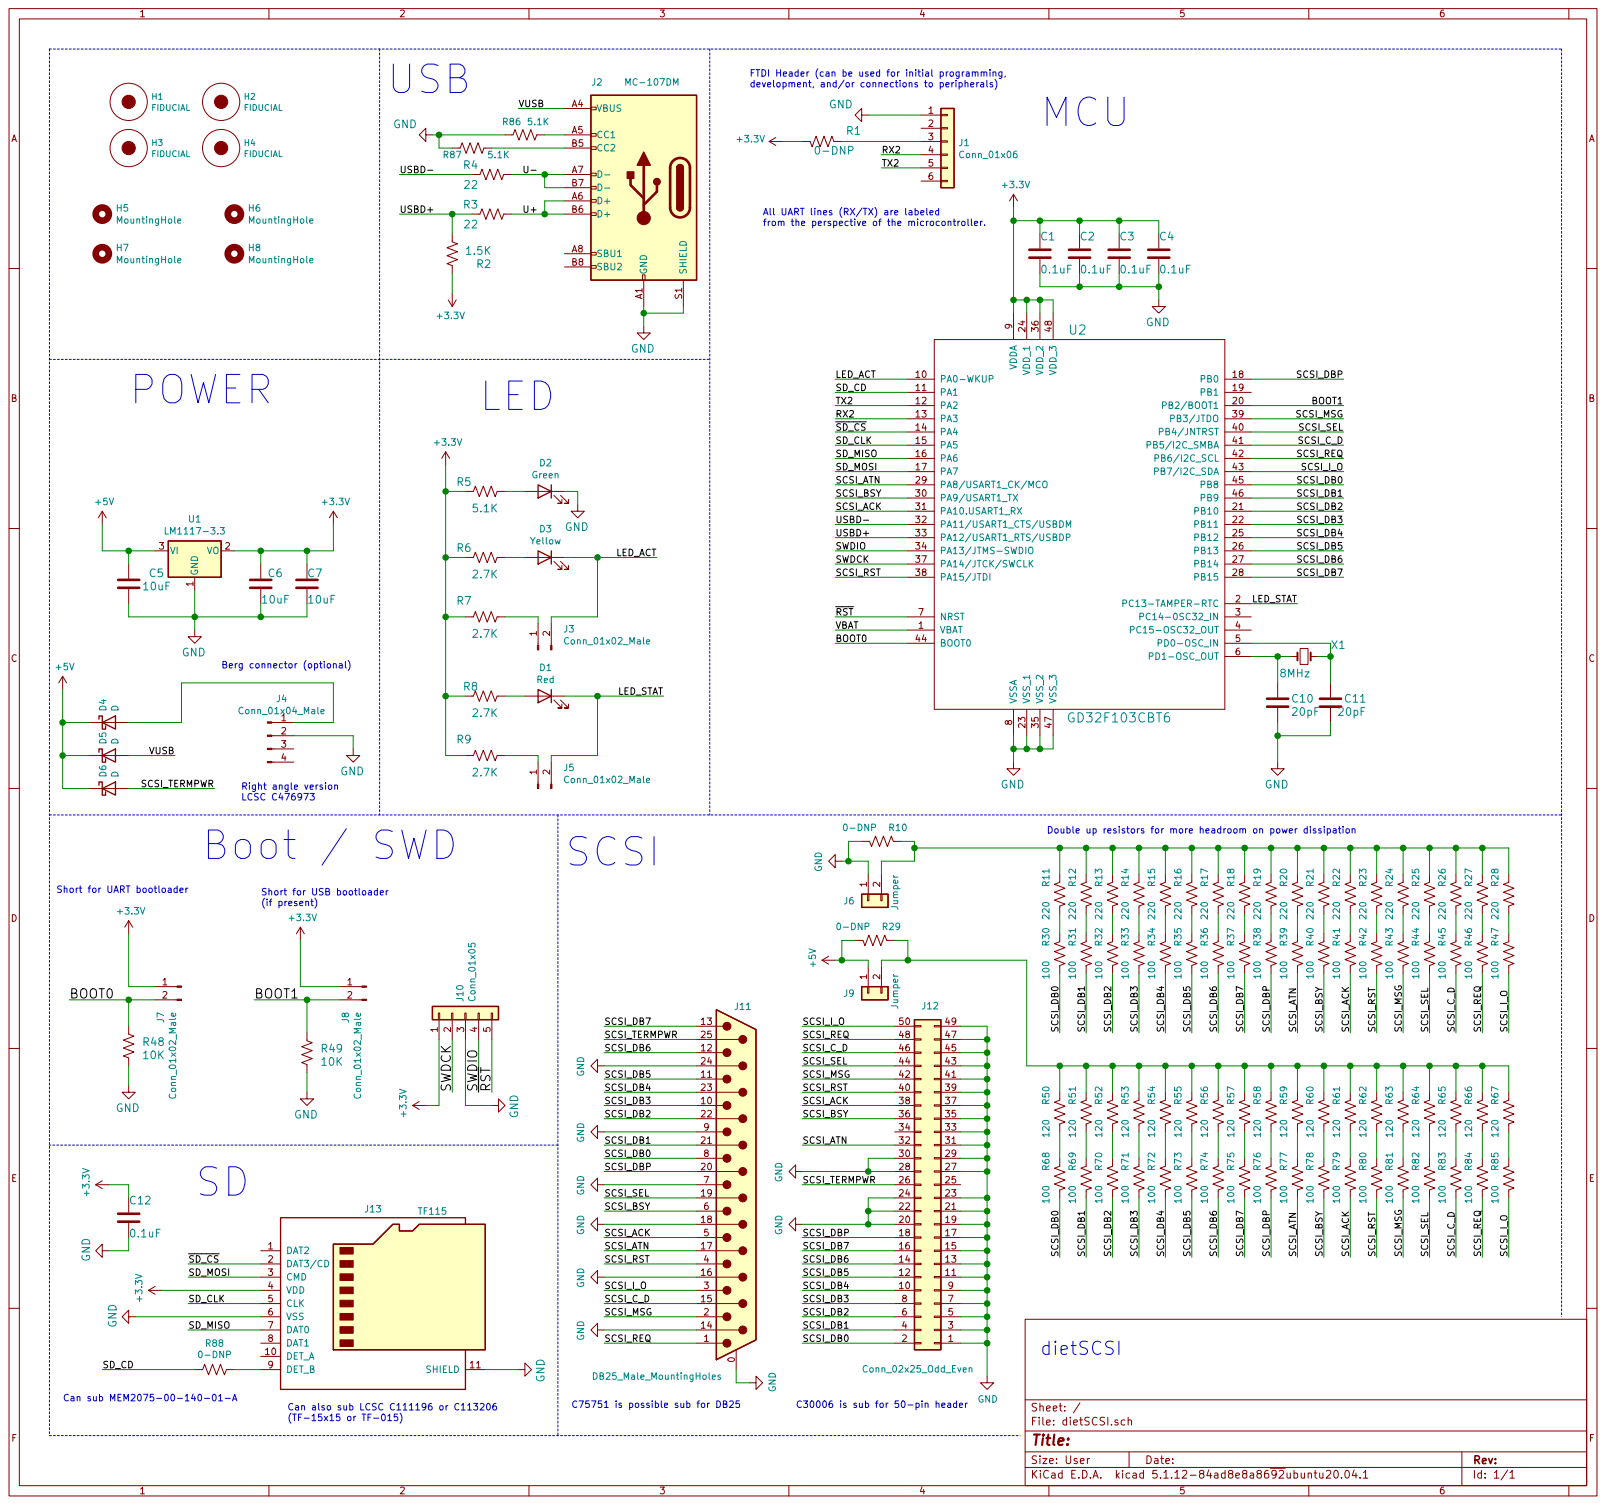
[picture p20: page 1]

FTDI Header (can be used for initial programming,
development, and/or connections to peripherals)

All UART lines (RX/TX) are labeled
from the perspective of the microcontroller.

Right angle version
LCSC C476973 Short for USB bootloader

Double up resistors for more headroom on power dissipation

Short for UART bootloader

C75751 is possible sub for DB25

C30006 is sub for 50-pin header

Id: 1/1 Title: File: dietSCSI.sch Sheet: /

Can also sub LCSC C111196 or C113206

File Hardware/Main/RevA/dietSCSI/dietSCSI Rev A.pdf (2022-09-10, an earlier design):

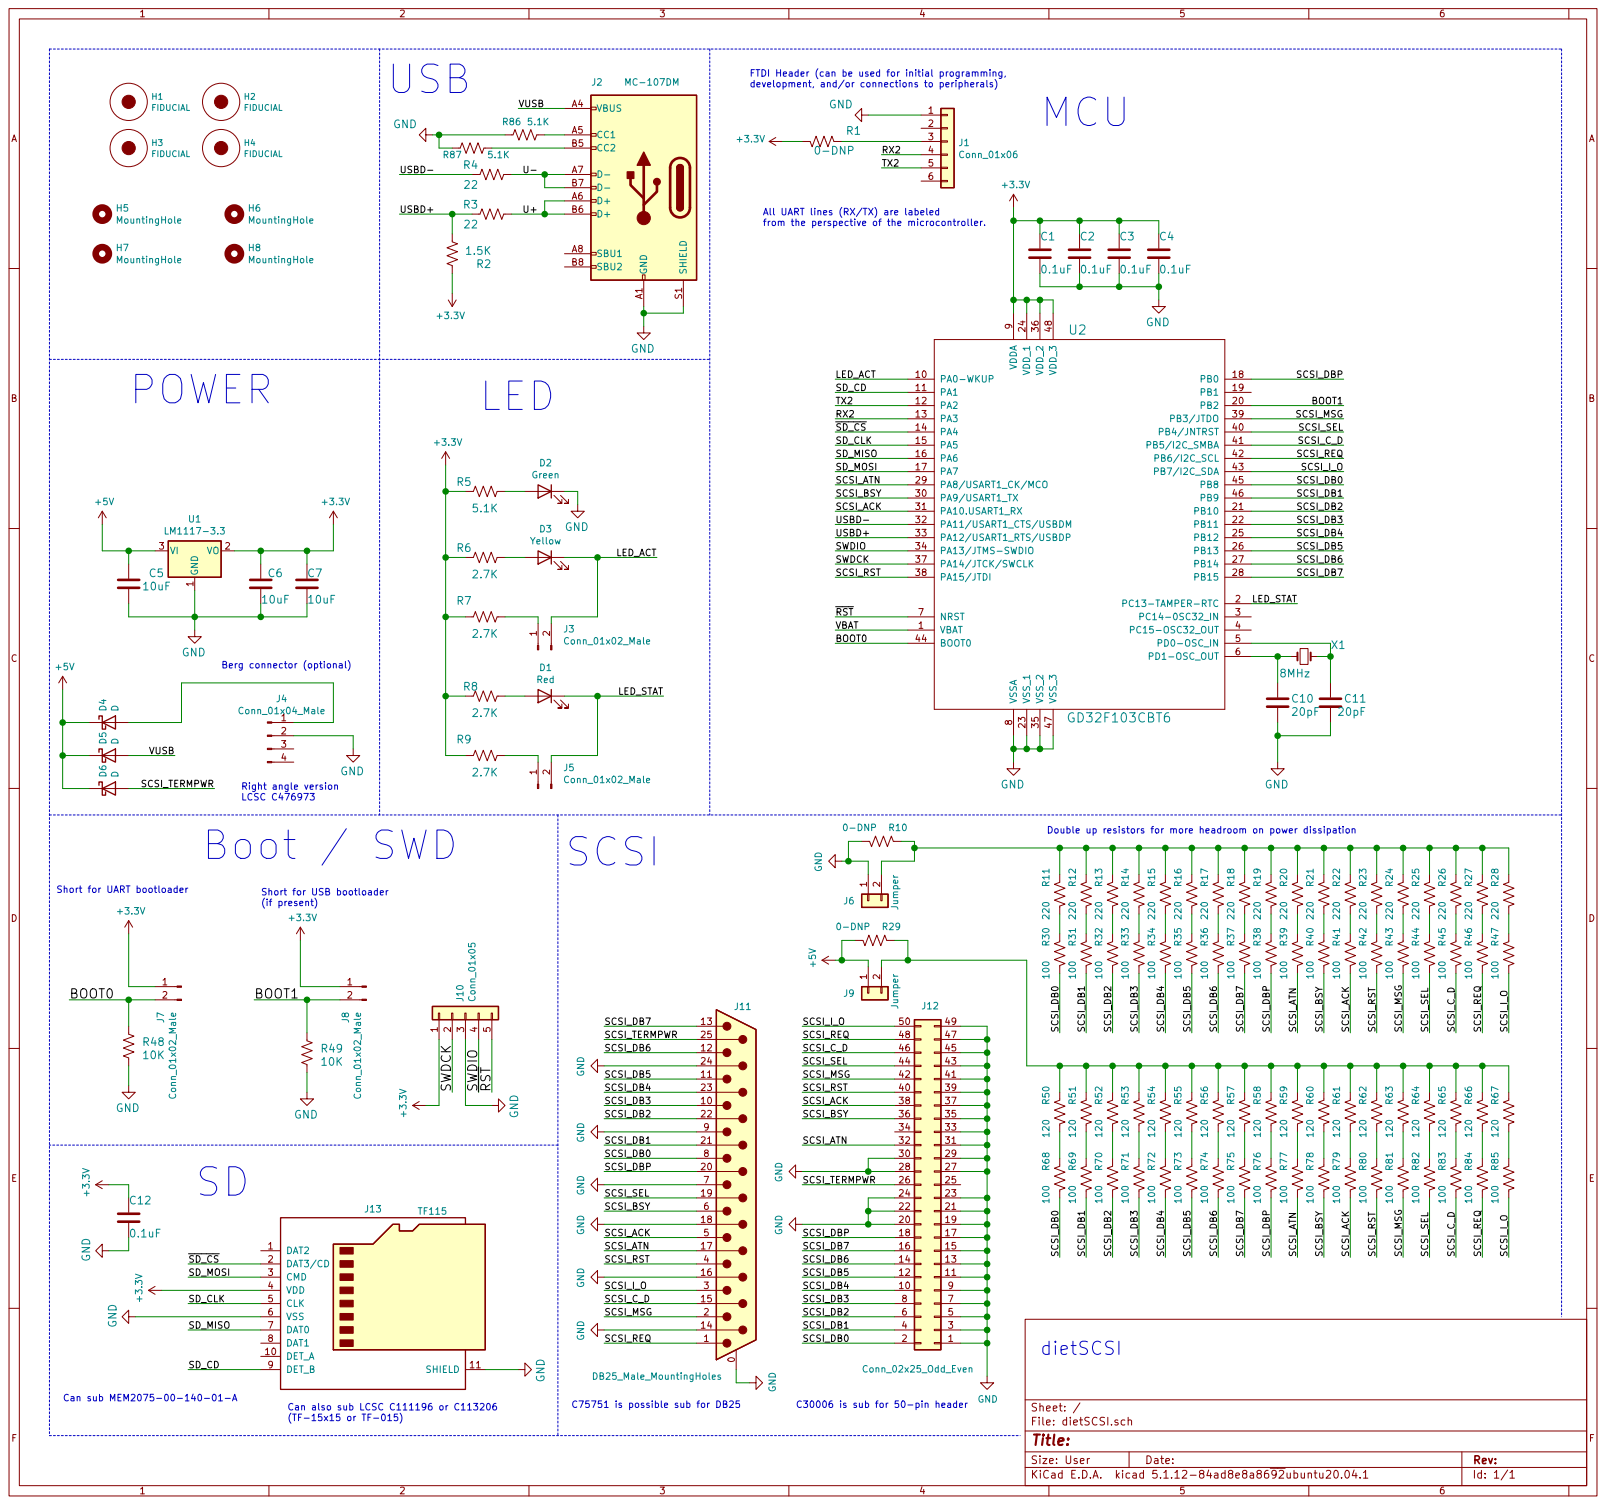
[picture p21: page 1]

FTDI Header (can be used for initial programming,
development, and/or connections to peripherals)

All UART lines (RX/TX) are labeled
from the perspective of the microcontroller.

SCSI_DB7 SCSI_DB6 SCSI_DB5 VUSB
LCSC C476973 Can also sub LCSC C111196 or C113206
Boot / SWD

Double up resistors for more headroom on power dissipation

C30006 is sub for 50-pin header Can sub MEM2075-00-140-01-ASD

C75751 is possible sub for DB25

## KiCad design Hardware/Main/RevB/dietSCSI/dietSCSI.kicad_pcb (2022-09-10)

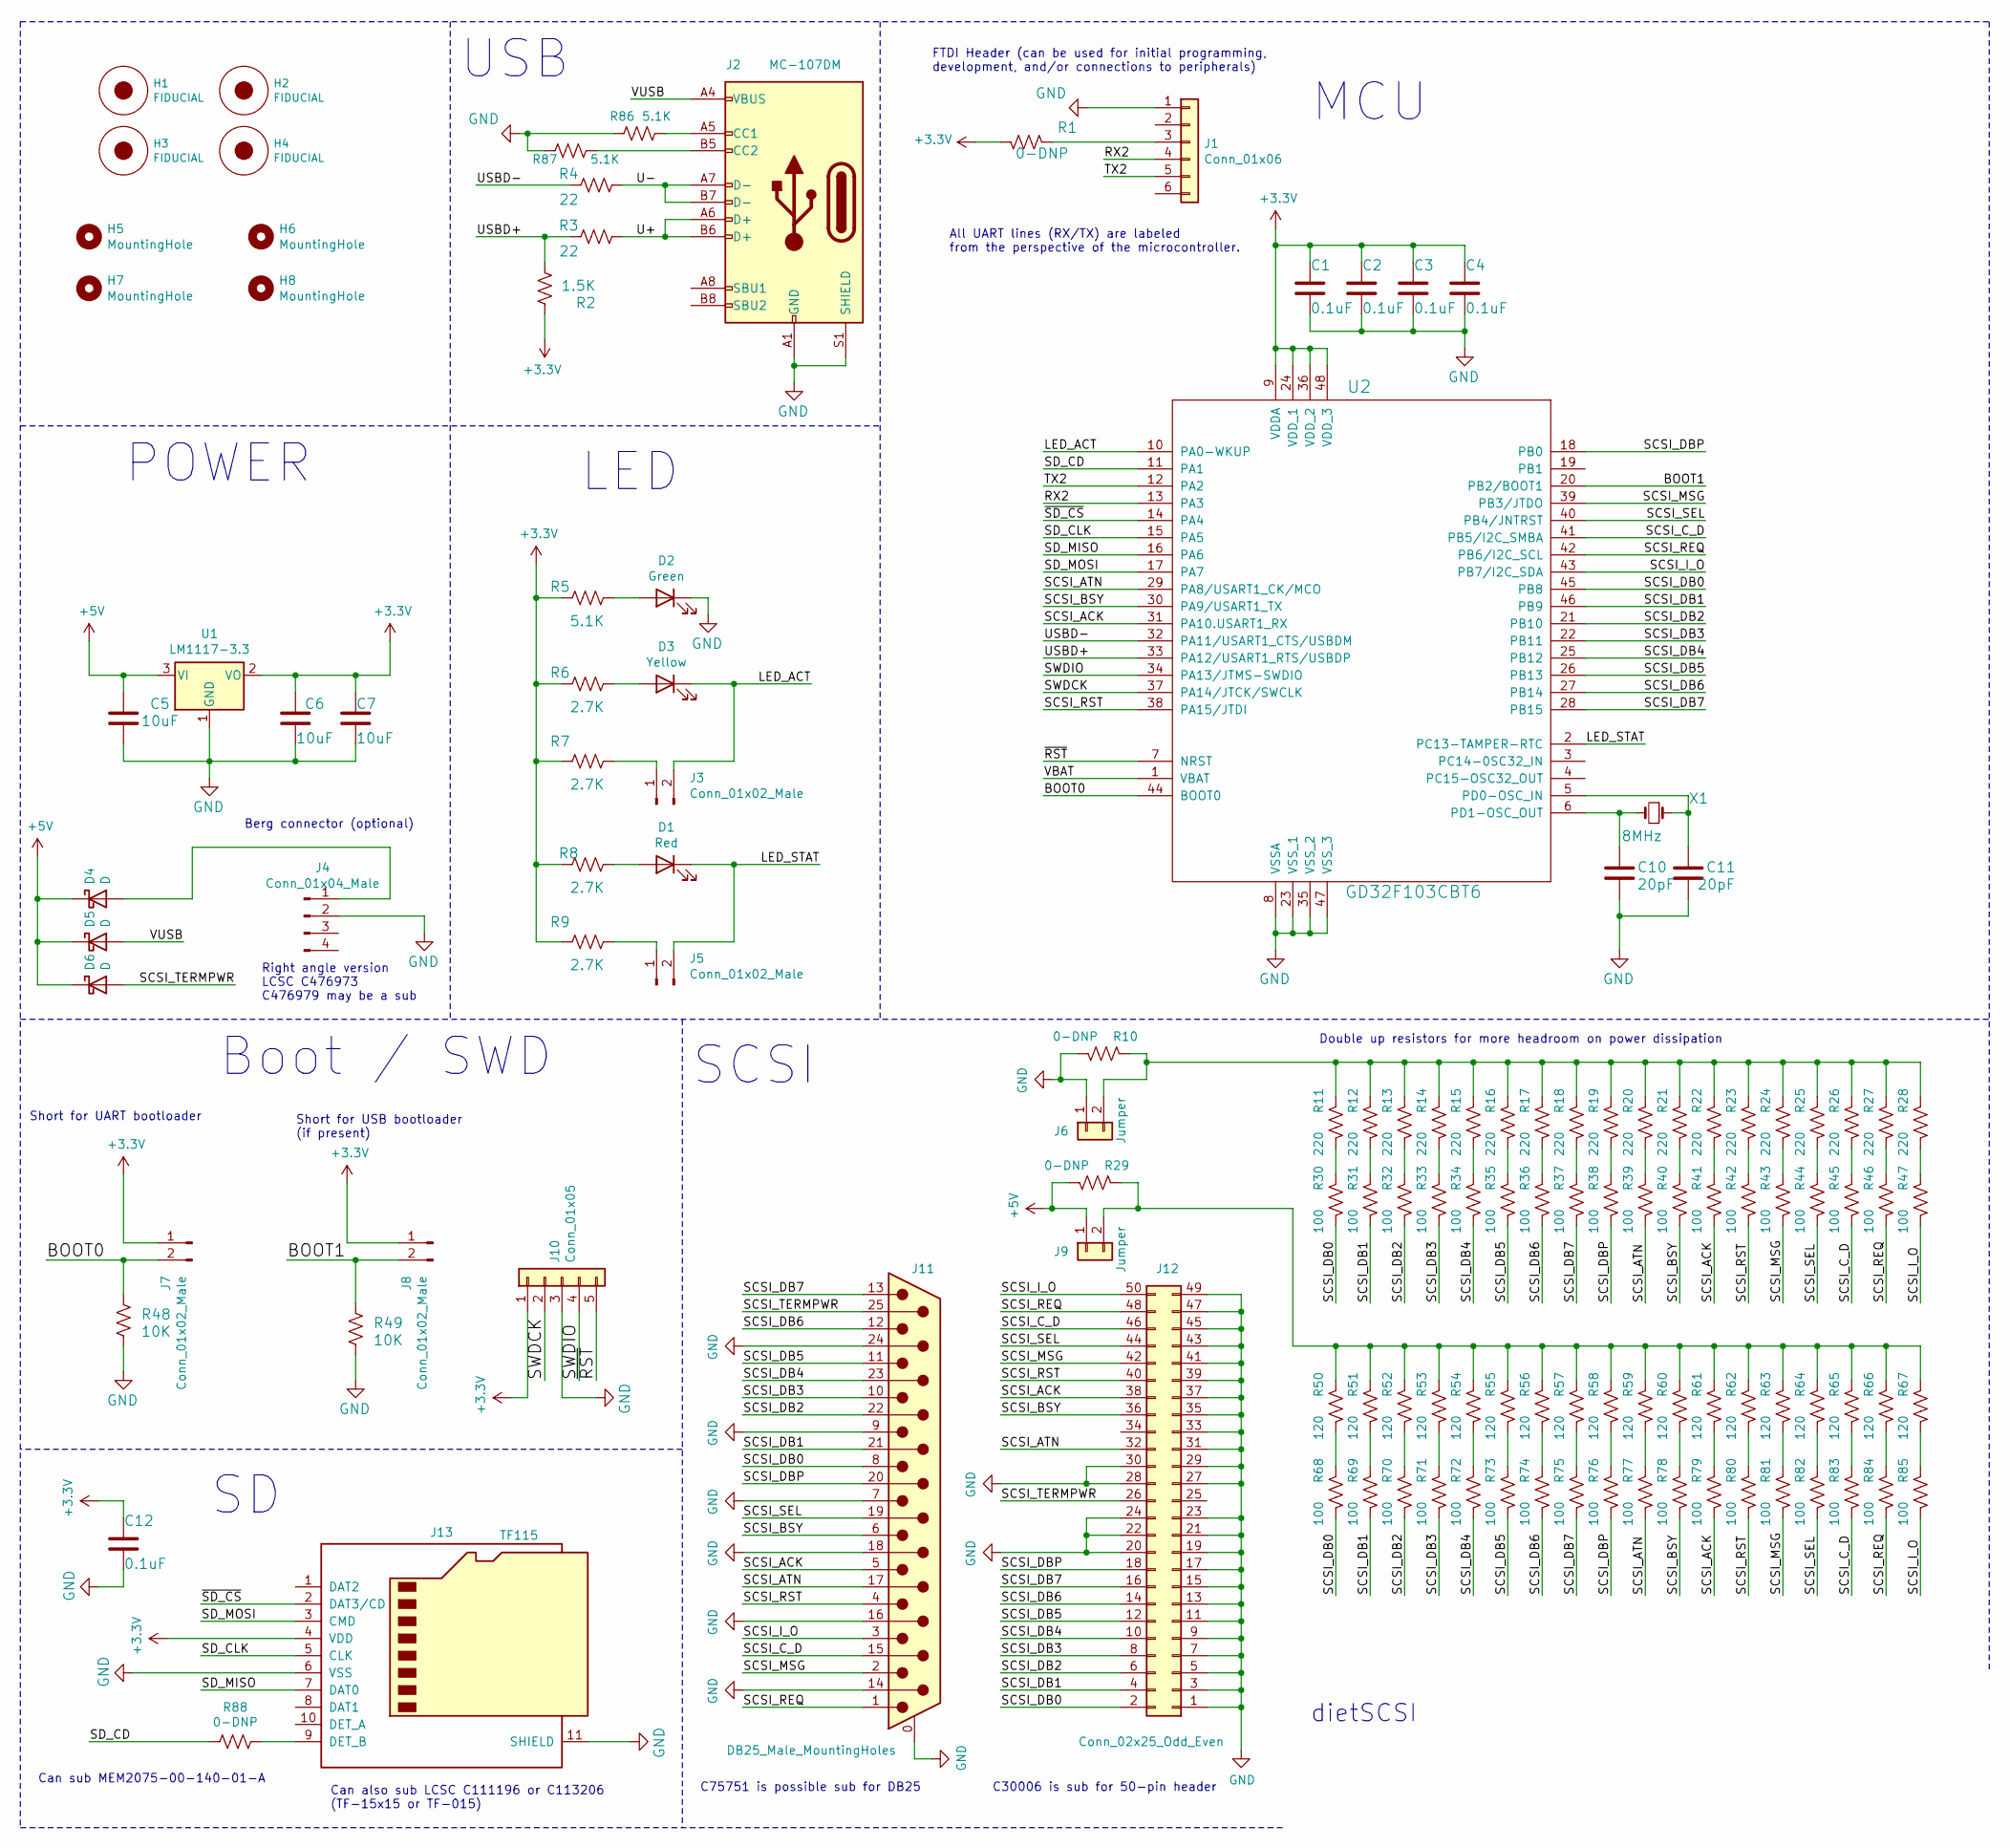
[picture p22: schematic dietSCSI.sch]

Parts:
C1, C2, C3, C4, C12: 0.1uF; C_0805_2012Metric_Pad1.18x1.45mm_HandSolder; JLCPCB C49678
C5, C6, C7: 10uF; C_1206_3216Metric_Pad1.33x1.80mm_HandSolder; JLCPCB C13585
C10, C11: 20pF; C_0805_2012Metric_Pad1.18x1.45mm_HandSolder; JLCPCB C1798
D1: Red; LED_0805_2012Metric_Pad1.15x1.40mm_HandSolder; JLCPCB C84256
D2: Green; LED_0805_2012Metric_Pad1.15x1.40mm_HandSolder; JLCPCB C2297
D3: Yellow; LED_0805_2012Metric_Pad1.15x1.40mm_HandSolder; JLCPCB C2296
D4, D5, D6: D; D_SOD-123; JLCPCB C8598
H1, H2, H3, H4: FIDUCIAL; Fiducial_1.5mm_Mask3mm
H5, H6, H7, H8: MountingHole; MountingHole_3mm_Pad
J1: Conn_01x06; PinHeader_1x06_P2.54mm_Vertical
J2: MC-107DM; USB_C_Receptacle_XKB_U262-16XN-4BVC11; JLCPCB C2874569
J3, J5, J7, J8: Conn_01x02_Male; PinHeader_1x02_P2.54mm_Vertical
J4: Conn_01x04_Male; BERG_4PIN; JLCPCB C210162
J6, J9: Jumper; PinHeader_1x02_P2.54mm_Vertical; JLCPCB C2894925
J10: Conn_01x05; PinHeader_1x05_P2.54mm_Vertical
J11: DB25_Male_MountingHoles; DSUB-25_Male_Horizontal_P2.77x2.84mm_EdgePinOffset7.70mm_Ho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; JLCPCB C190082
J12: Conn_02x25_Odd_Even; PinHeader_2x25_P2.54mm_Vertical_Shrouded; JLCPCB C601945
J13: TF115; TF-015_MEM2075_HYBRID; JLCPCB C266620
R1, R10, R29: 0-DNP; R_0805_2012Metric_Pad1.20x1.40mm_HandSolder
R2: 1.5K; R_0805_2012Metric_Pad1.20x1.40mm_HandSolder; JLCPCB C4310
R3, R4: 22; R_0805_2012Metric_Pad1.20x1.40mm_HandSolder; JLCPCB C17561
R5, R86, R87: 5.1K; R_0805_2012Metric_Pad1.20x1.40mm_HandSolder; JLCPCB C27834
R6, R7, R8, R9: 2.7K; R_0805_2012Metric_Pad1.20x1.40mm_HandSolder; JLCPCB C17530
R11, R12, R13, R14, R15, R16, R17, R18, R19, R20, R21, R22, R23, R24, R25, R26, R27, R28: 220; R_0805_2012Metric_Pad1.20x1.40mm_HandSolder; JLCPCB C17557
R30, R31, R32, R33, R34, R35, R36, R37, R38, R39, R40, R41, R42, R43, R44, R45, R46, R47, R68, R69, R70, R71, R72, R73, R74, R75, R76, R77, R78, R79, R80, R81, R82, R83, R84, R85: 100; R_0805_2012Metric_Pad1.20x1.40mm_HandSolder; JLCPCB C17408
R48, R49: 10K; R_0805_2012Metric_Pad1.20x1.40mm_HandSolder; JLCPCB C17414
R50, R51, R52, R53, R54, R55, R56, R57, R58, R59, R60, R61, R62, R63, R64, R65, R66, R67: 120; R_0805_2012Metric_Pad1.20x1.40mm_HandSolder; JLCPCB C17437
R88: 0-DNP; R_0402_1005Metric
U1: LM1117-3.3; SOT-223-3_TabPin2; JLCPCB C6186
U2: GD32F103CBT6; LQFP-48_7x7mm_P0.5mm; JLCPCB C77979
X1: 8MHz; Crystal_SMD_5032-2Pin_5.0x3.2mm; JLCPCB C115962

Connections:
+3V3: C1.1, C2.1, C3.1, C4.1, C6.1, C7.1, C12.1, J7.1, J8.1, J10.1, J13.4 (VDD), R1.1, R2.1, R5.1, R6.1, R7.1, R8.1, R9.1, U1.2 (VO), U2.9 (VDDA), U2.24 (VDD_1), U2.36 (VDD_2), U2.48 (VDD_3)
+5V: C5.1, D4.1 (K), D5.1 (K), D6.1 (K), J9.1, R29.2, U1.3 (VI)
/BOOT0: J7.2, R48.1, U2.44 (BOOT0)
/BOOT1: J8.2, R49.1, U2.20 (PB2/BOOT1)
/LED_ACT: D3.1 (K), J3.2, U2.10 (PA0-WKUP)
/LED_STAT: D1.1 (K), J5.2, U2.2 (PC13-TAMPER-RTC)
/RX2: J1.4, U2.13 (PA3)
/SCSI_ACK: J11.5, J12.38, R41.2, R79.2, U2.31 (PA10.USART1_RX)
/SCSI_ATN: J11.17, J12.32, R39.2, R77.2, U2.29 (PA8/USART1_CK/MCO)
/SCSI_BSY: J11.6, J12.36, R40.2, R78.2, U2.30 (PA9/USART1_TX)
/SCSI_C_D: J11.15, J12.46, R45.2, R83.2, U2.41 (PB5/I2C_SMBA)
/SCSI_DB0: J11.8, J12.2, R30.2, R68.2, U2.45 (PB8)
/SCSI_DB1: J11.21, J12.4, R31.2, R69.2, U2.46 (PB9)
/SCSI_DB2: J11.22, J12.6, R32.2, R70.2, U2.21 (PB10)
/SCSI_DB3: J11.10, J12.8, R33.2, R71.2, U2.22 (PB11)
/SCSI_DB4: J11.23, J12.10, R34.2, R72.2, U2.25 (PB12)
/SCSI_DB5: J11.11, J12.12, R35.2, R73.2, U2.26 (PB13)
/SCSI_DB6: J11.12, J12.14, R36.2, R74.2, U2.27 (PB14)
/SCSI_DB7: J11.13, J12.16, R37.2, R75.2, U2.28 (PB15)
/SCSI_DBP: J11.20, J12.18, R38.2, R76.2, U2.18 (PB0)
/SCSI_I_O: J11.3, J12.50, R47.2, R85.2, U2.43 (PB7/I2C_SDA)
/SCSI_MSG: J11.2, J12.42, R43.2, R81.2, U2.39 (PB3/JTDO)
/SCSI_REQ: J11.1, J12.48, R46.2, R84.2, U2.42 (PB6/I2C_SCL)
/SCSI_RST: J11.4, J12.40, R42.2, R80.2, U2.38 (PA15/JTDI)
/SCSI_SEL: J11.19, J12.44, R44.2, R82.2, U2.40 (PB4/JNTRST)
/SCSI_TERMPWR: D6.2 (A), J11.25, J12.26
/SD_CD: R88.2, U2.11 (PA1)
/SD_CLK: J13.5 (CLK), U2.15 (PA5)
/SD_MISO: J13.7 (DAT0), U2.16 (PA6)
/SD_MOSI: J13.3 (CMD), U2.17 (PA7)
/SWDCK: J10.2, U2.37 (PA14/JTCK/SWCLK)
/SWDIO: J10.4, U2.34 (PA13/JTMS-SWDIO)
/TX2: J1.5, U2.12 (PA2)
/U+: J2.A6 (D+), J2.B6 (D+), R3.2
/U-: J2.A7 (D-), J2.B7 (D-), R4.2
/USBD+: R2.2, R3.1, U2.33 (PA12/USART1_RTS/USBDP)
/USBD-: R4.1, U2.32 (PA11/USART1_CTS/USBDM)
/VBAT: U2.1 (VBAT)
/VUSB: D5.2 (A), J2.A4 (VBUS), J2.A9 (VBUS), J2.B4 (VBUS), J2.B9 (VBUS)
/~RST: J10.5, U2.7 (NRST)
/~SD_CS: J13.2 (DAT3/CD), U2.14 (PA4)
GND: C1.2, C2.2, C3.2, C4.2, C5.2, C6.2, C7.2, C10.2, C11.2, C12.2, D2.1 (K), J1.1, J2.A1 (GND), J2.A12 (GND), J2.B1 (GND), J2.B12 (GND), J2.S1 (SHIELD), J4.2, J6.1, J10.3, J11.0 (PAD), J11.7, J11.9, J11.14, J11.16, J11.18, J11.24, J12.1, J12.3, J12.5, J12.7, J12.9, J12.11, J12.13, J12.15, J12.17, J12.19, J12.20, J12.21, J12.22, J12.23, J12.24, J12.27, J12.28, J12.29, J12.30, J12.31, J12.33, J12.35, J12.37, J12.39, J12.41, J12.43, J12.45, J12.47, J12.49, J13.6 (VSS), J13.11 (SHIELD), R10.2, R48.2, R49.2, R86.2, R87.2, U1.1 (GND), U2.8 (VSSA), U2.23 (VSS_1), U2.35 (VSS_2), U2.47 (VSS_3)
unnamed: C10.1, U2.6 (PD1-OSC_OUT), X1.2
unnamed: C11.1, U2.5 (PD0-OSC_IN), X1.1
unnamed: D1.2 (A), R8.2
unnamed: D2.2 (A), R5.2
unnamed: D3.2 (A), R6.2
unnamed: D4.2 (A), J4.1
unnamed: J1.3, R1.2
unnamed: J2.A5 (CC1), R86.1
unnamed: J2.B5 (CC2), R87.1
unnamed: J3.1, R7.2
unnamed: J5.1, R9.2
unnamed: J6.2, R10.1, R11.1, R12.1, R13.1, R14.1, R15.1, R16.1, R17.1, R18.1, R19.1, R20.1, R21.1, R22.1, R23.1, R24.1, R25.1, R26.1, R27.1, R28.1
unnamed: J9.2, R29.1, R50.1, R51.1, R52.1, R53.1, R54.1, R55.1, R56.1, R57.1, R58.1, R59.1, R60.1, R61.1, R62.1, R63.1, R64.1, R65.1, R66.1, R67.1
unnamed: J13.9 (DET_B), R88.1
unnamed: R11.2, R30.1
unnamed: R12.2, R31.1
unnamed: R13.2, R32.1
unnamed: R14.2, R33.1
unnamed: R15.2, R34.1
unnamed: R16.2, R35.1
unnamed: R17.2, R36.1
unnamed: R18.2, R37.1
unnamed: R19.2, R38.1
unnamed: R20.2, R39.1
unnamed: R21.2, R40.1
unnamed: R22.2, R41.1
unnamed: R23.2, R42.1
unnamed: R24.2, R43.1
unnamed: R25.2, R44.1
unnamed: R26.2, R45.1
unnamed: R27.2, R46.1
unnamed: R28.2, R47.1
unnamed: R50.2, R68.1
unnamed: R51.2, R69.1
unnamed: R52.2, R70.1
unnamed: R53.2, R71.1
unnamed: R54.2, R72.1
unnamed: R55.2, R73.1
unnamed: R56.2, R74.1
unnamed: R57.2, R75.1
unnamed: R58.2, R76.1
unnamed: R59.2, R77.1
unnamed: R60.2, R78.1
unnamed: R61.2, R79.1
unnamed: R62.2, R80.1
unnamed: R63.2, R81.1
unnamed: R64.2, R82.1
unnamed: R65.2, R83.1
unnamed: R66.2, R84.1
unnamed: R67.2, R85.1

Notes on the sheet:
dietSCSI
Boot / SWD
MCU
LED
USB
Short for UART bootloader
Short for USB bootloader (if present)
FTDI Header (can be used for initial programming, development, and/or connections to peripherals)
All UART lines (RX/TX) are labeled from the perspective of the microcontroller.
SCSI
POWER
Berg connector (optional)
Right angle version LCSC C476973 C476979 may be a sub
Can also sub LCSC C111196 or C113206 (TF-15x15 or TF-015)
Double up resistors for more headroom on power dissipation
Can sub MEM2075-00-140-01-A
C75751 is possible sub for DB25
C30006 is sub for 50-pin header

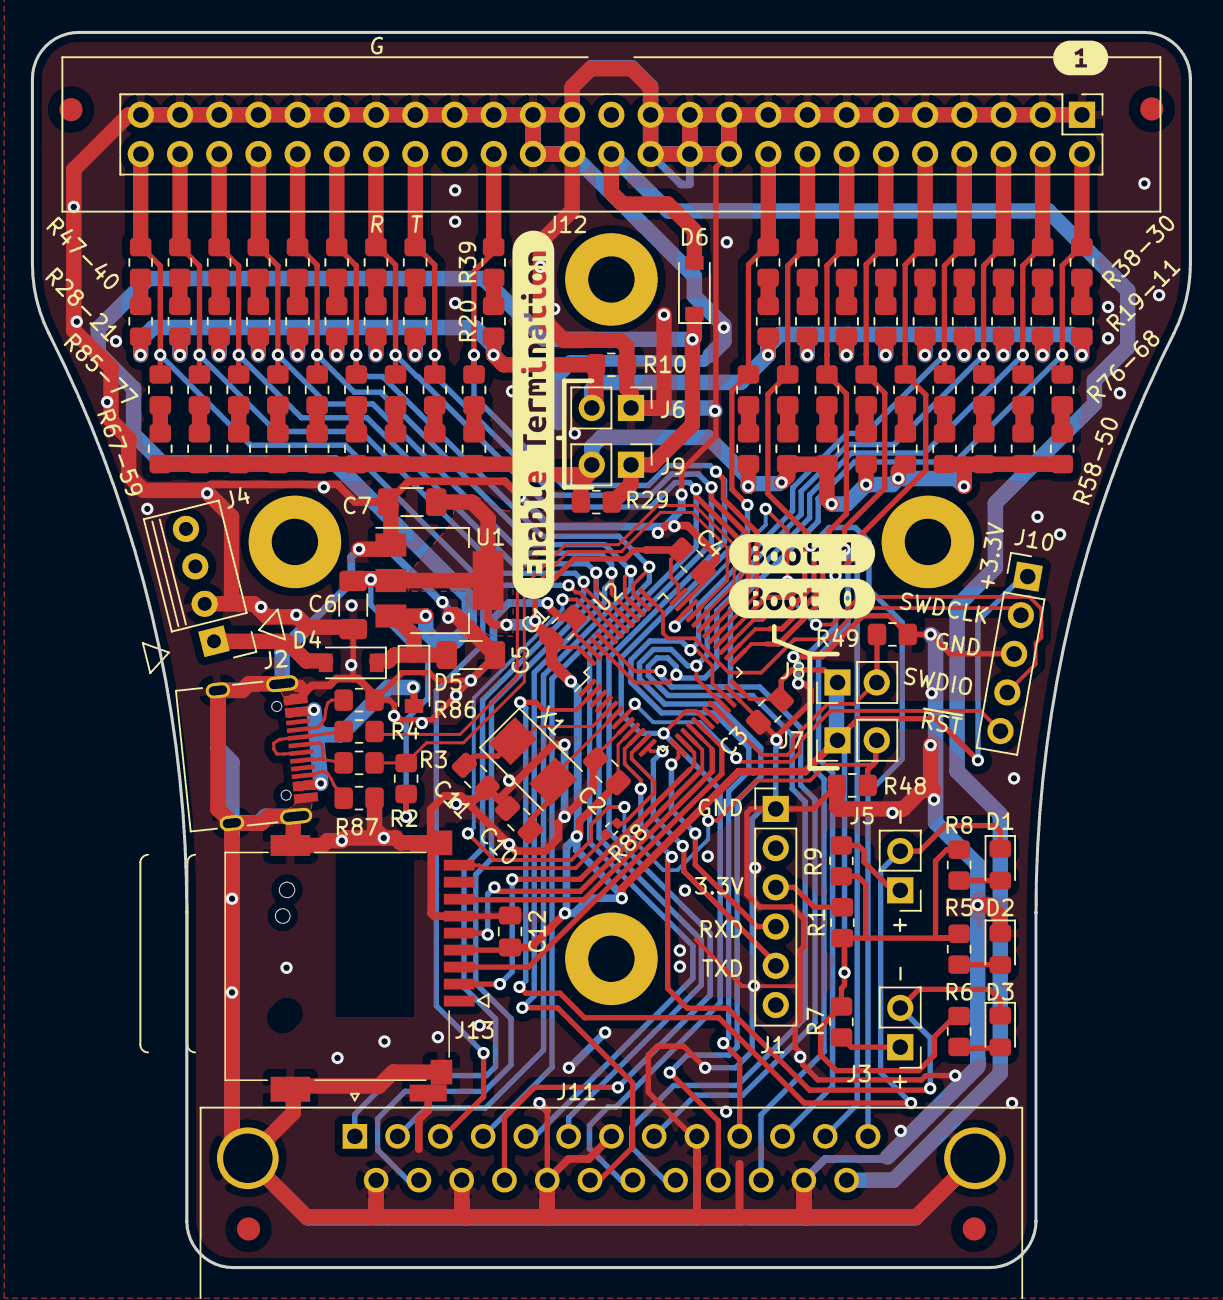
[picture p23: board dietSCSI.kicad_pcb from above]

Board: 2 copper layers, 75.0 x 80.0 mm, 133 parts (1 on the bottom side), 91 nets.

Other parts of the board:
kibuzzard-61DE6C26, kibuzzard-61DE6C26#2, kibuzzard-62F7F5F5, kibuzzard-62F7F550, kibuzzard-62F7F576: G***; label

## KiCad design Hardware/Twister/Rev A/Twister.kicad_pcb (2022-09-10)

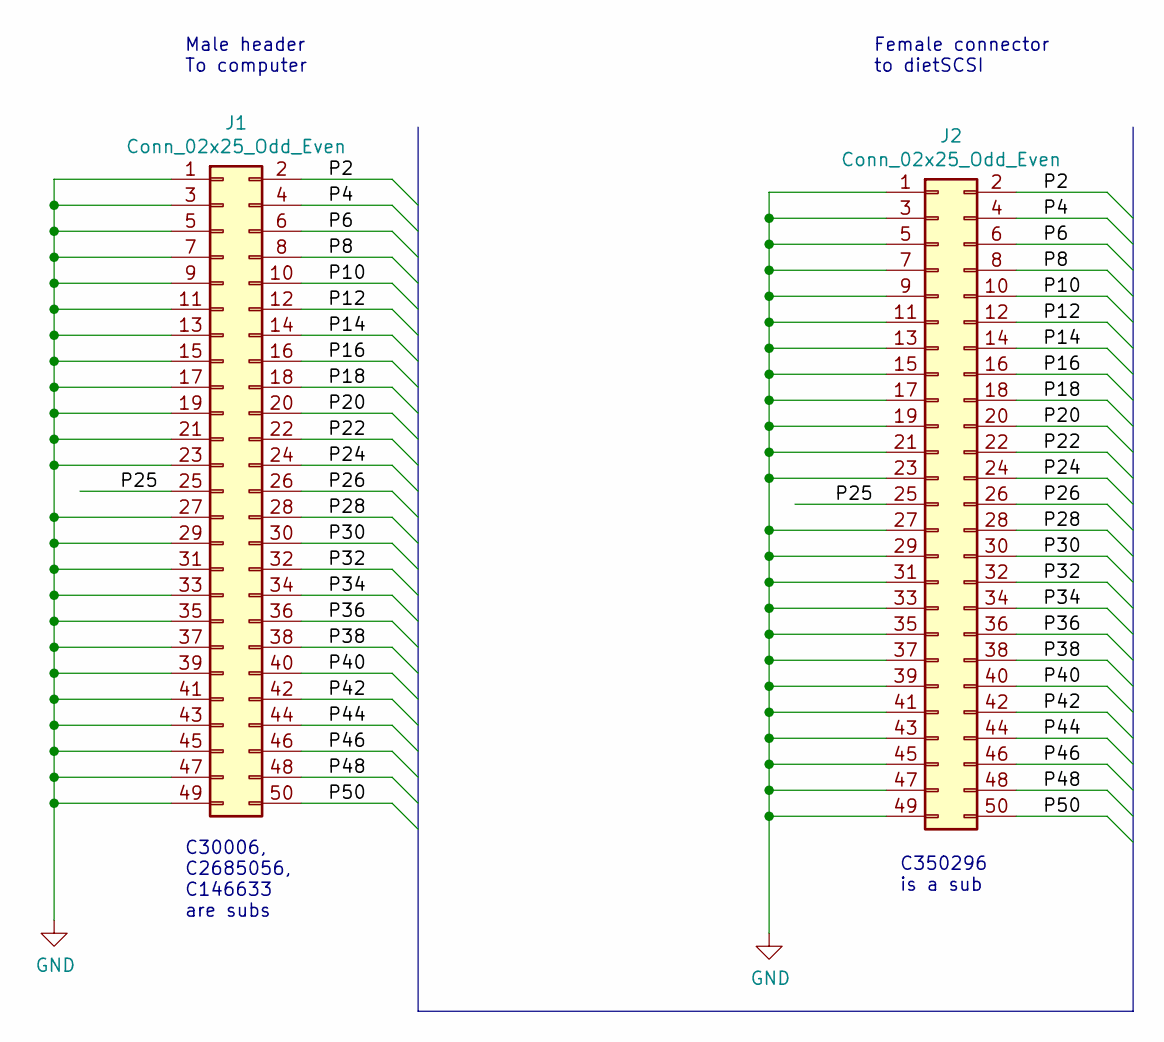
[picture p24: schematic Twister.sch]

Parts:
J1: Conn_02x25_Odd_Even; PinHeader_2x25_P2.54mm_Vertical_Shrouded; Digikey ED10530-ND
J2: Conn_02x25_Odd_Even; PinSocket_2x25_P2.54mm_Vertical; JLCPCB C40024

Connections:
/P2: J1.2, J2.2
/P4: J1.4, J2.4
/P6: J1.6, J2.6
/P8: J1.8, J2.8
/P10: J1.10, J2.10
/P12: J1.12, J2.12
/P14: J1.14, J2.14
/P16: J1.16, J2.16
/P18: J1.18, J2.18
/P20: J1.20, J2.20
/P22: J1.22, J2.22
/P24: J1.24, J2.24
/P25: J1.25, J2.25
/P26: J1.26, J2.26
/P28: J1.28, J2.28
/P30: J1.30, J2.30
/P32: J1.32, J2.32
/P34: J1.34, J2.34
/P36: J1.36, J2.36
/P38: J1.38, J2.38
/P40: J1.40, J2.40
/P42: J1.42, J2.42
/P44: J1.44, J2.44
/P46: J1.46, J2.46
/P48: J1.48, J2.48
/P50: J1.50, J2.50
GND: J1.1, J1.3, J1.5, J1.7, J1.9, J1.11, J1.13, J1.15, J1.17, J1.19, J1.21, J1.23, J1.27, J1.29, J1.31, J1.33, J1.35, J1.37, J1.39, J1.41, J1.43, J1.45, J1.47, J1.49, J2.1, J2.3, J2.5, J2.7, J2.9, J2.11, J2.13, J2.15, J2.17, J2.19, J2.21, J2.23, J2.27, J2.29, J2.31, J2.33, J2.35, J2.37, J2.39, J2.41, J2.43, J2.45, J2.47, J2.49

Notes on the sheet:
Male header To computer
Female connector to dietSCSI
C30006, C2685056, C146633 are subs
C350296 is a sub

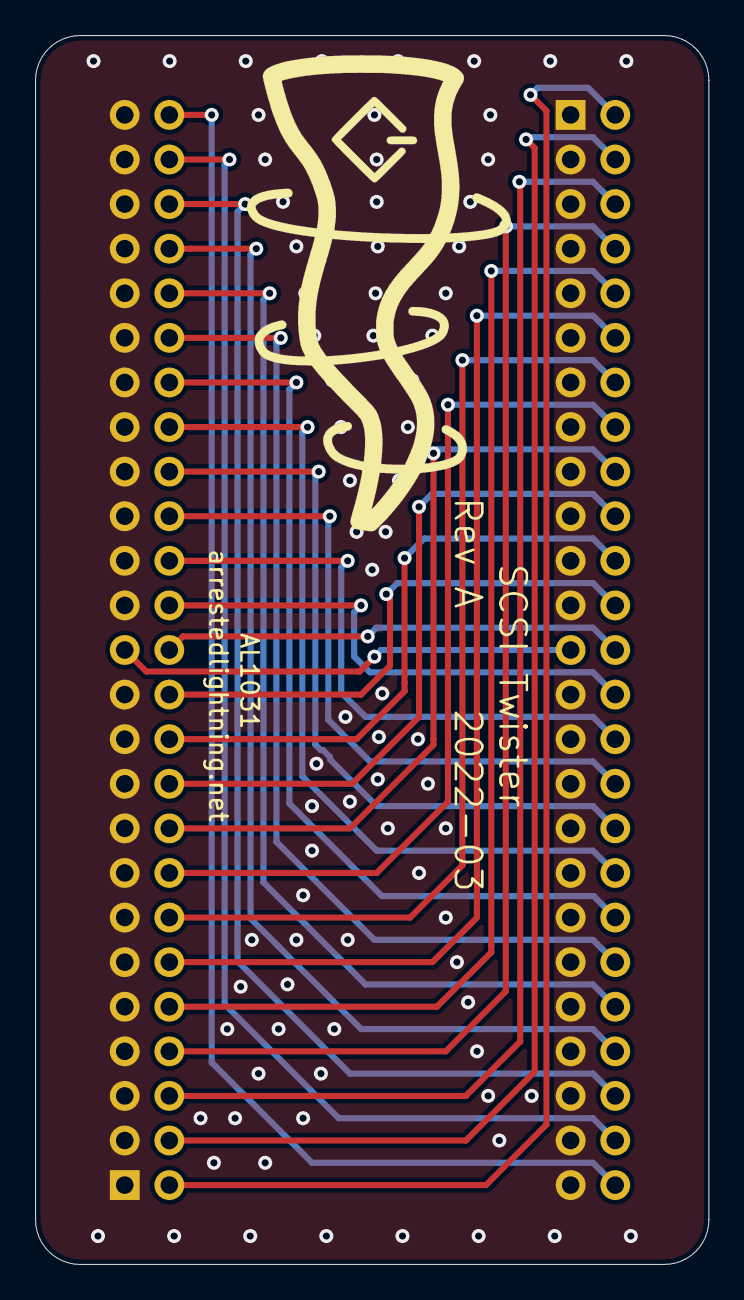
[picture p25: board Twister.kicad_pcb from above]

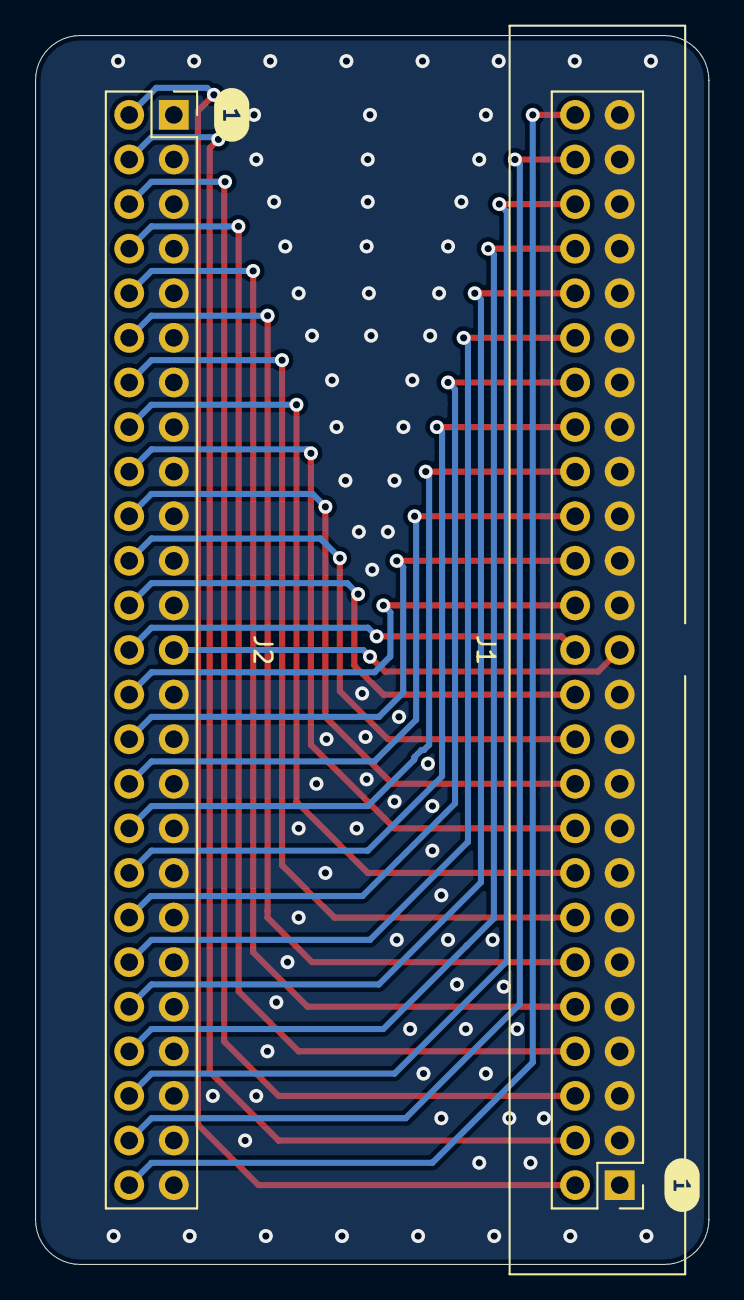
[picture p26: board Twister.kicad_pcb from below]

Board: 2 copper layers, 38.4 x 70.0 mm, 4 parts (4 on the bottom side), 27 nets.

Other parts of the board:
kibuzzard-622EC2D7, kibuzzard-622EC2D7#2: G***; label
